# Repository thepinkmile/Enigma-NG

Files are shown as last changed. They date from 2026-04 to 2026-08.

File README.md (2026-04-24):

# Enigma NG: Digital Cryptography Ecosystem

The Enigma-NG is an advanced "Museum-Grade", modular, and historically-accurate digital recreation of the world’s most iconic encryption machines.
Powered by a **Raspberry Pi Compute Module 5 (CM5)**, this system controls a hardware stack of up to 30 custom CPLD-based rotors and a physical 64-jack plugboard.
Powered with either USB-C Power Adapter, PoE+ or Smart Battery. It bridges 1940s mechanical heritage with 2026 high-speed digital engineering.

## 🚀 Project Vision

To create a high-fidelity, educational, and industrially robust encryption platform.
The design prioritises classroom safety, professional EMI shielding, and deep hardware visibility for students via an integrated diagnostic bank.
Beyond a simple Enigma clone, this terminal is a **Universal Cipher Engine**. The hardware is designed to emulate:

* **Enigma Variants:** I, M3, M4, and Abwehr.
* **Typex:** The 5-rotor British adaptation with simulated printer output.
* **SIGABA:** The 15-rotor US system using complex 3-bank stepping algorithms.
* **NG-26** The modern digital enigma machine designed and created by Matthew McAtamney-Greenwood.

One of the long-term goals of this project is to introduce the ability to deliver Enigma encrypted data over the network,
and even provide the ability to deliver encrypted files using a base-64 encoding before executing the standard rotor-based encryption.
This end-goal will involve the definition of a new RFC for the "Enigma-Packet-Protocol (EnPP)", which will be a custom specification for this project's ecosystem.

## Tools Used

* **Visual Studio Code:** To manage the Documentation within this repository.
* **Visual Studio:** (Latest Community Edition) To develop the GUI Application.
* **KiCAD 9:** To develop the electrical components and PCB layouts.
* **OnShape:** To create and manage the mechanical designs and assemblies.
* **Yocto:** To create the custom Linux OS with built-in drivers and GUI Application.

## Core Component Overview

* **Controller Board:** Raspberry Pi Compute Module 5 (CM5) carrier board hosting the fixed
  motherboard, external I/O, and service docks.
* **Power Module:** Removable power-conditioning / UPS cartridge with PoE, USB-C, smart-battery
  inputs, eFuse protection, and supercap-backed hold-up.
* **Stator Board:** Removable vertical daughterboard and CPLD routing hub for the rotor stack,
  encoder ports, reflector return, and Settings Board I2C link.
* **Rotor Module:** Repeated smart encryption unit (up to 30 fitted) with local CPLD and position
  sensing.
* **Extension Board:** 5-rotor group bridge used to regenerate JTAG timing and carry power /
  return-path continuity between rotor groups.
* **Reflector Board:** Mandatory passive turnaround board at the end of the rotor chain.
* **Encoder Module:** Single generic 64-line interface board reused in keyboard, lightboard, and
  plugboard encode / decode roles.
* **Settings Board:** Panel-mount switch and RGB indicator board on the shared Stator I2C-1 bus.
* **JTAG Daughterboard:** Internal FT232H-based USB-to-JTAG bridge for programming all system CPLDs.

## Core Requirements

* **Interface:** Controller ↔ Power Module uses three TE 10-position 2.5mm dock connectors; Controller
  ↔ Stator uses two Molex EXTreme Guardian HD hybrid docks.
* **Diagnostics:** Two ENIG diagnostic banks are provided on the Controller for the PM and Stator dock
  interfaces.
* **UI:** .NET 10.0 Cross-platform GUI with:
  * Live power telemetry.
  * Historical resources.
  * 3D graphical visualiser.
  * Configuration programmer (and creator).

## Board Status Snapshot

| Board | Status |
| :--- | :--- |
| Controller Board | In Review |
| Power Module | In Review |
| Stator Board | In Review |
| Rotor Module | In Review |
| Extension Board | In Review |
| Reflector Board | In Review |
| Encoder Module | In Review |
| Settings Board | In Review |
| JTAG Daughterboard | In Review |

---

## 🔌 Hardware Architecture

### 1. Power Module (The Heart)

* **Input:** Triple-input OR-ing between PoE+ 802.3bt Type 4, USB-C 15V PD, and Battery
  11–16.4V via LM74700-Q1 + CSD17483F4T ideal-diode FETs. PoE is explicitly prioritised over
  USB-C; USB-C vs Battery precedence follows the active input voltages unless extra gating is added.
* **PoE:** Fully discrete 802.3bt Type 4 front end — TPS2372-4 (PD interface) + TPS23730 (ACF DC-DC) + Coilcraft POE600F-12LD transformer stage. Implemented 12V power stage capacity: 60W.
* **Protection:** TPS25980 eFuse — 7A ILIM, 11.0V UVLO, 16.9V OVLO, 3mΩ RON. Plus 72°C TCO thermal fuse.
* **Buck:** Dual-phase interleaved LMQ61460-Q1 (×2, 6A each, 12A combined, 400kHz DRSS, 180° SYNC). Effective ripple: 800kHz.
* **LDO:** TPS75733KTTRG3 3V3_ENIG (8.8µVRMS noise, 72dB PSRR, 3A, 2.05 A typical load at 68.3% utilisation).
* **UPS:** LTC3350 supercap manager + 8× Abracon ADCR-T02R7SA256MB (2S4P, 50 F) on 5V_MAIN bus. 50 F at 5.4V → ≥33.5 second hold-up for clean CM5 shutdown.
* **Output Rails:** 5V_MAIN (12A) and 3V3_ENIG (3A — logic, CPLDs, and rotor stack) via 80-pin Samtec ERF8 BtB to Controller Board for distribution.
* **Panel Controls:** SW1 is a rugged latching RGB power toggle (Adafruit 4660) and SW2 is a
  matching 16mm momentary RGB CM5 power button (Adafruit 3350); both are panel-mounted controls
  wired to the Power Module harness.

### 2. Controller Board (The Brain)

* **Module:** Raspberry Pi CM5 (BCM2712) on a custom 6-layer 2oz carrier.
* **Power Input:** 3-way seamless switching (LM74700-Q1 ideal-diode on Power Module).
  * **Smart Battery:** 5-pin Molex Micro-Fit connector (11V-16.4V nominal) with SMBus telemetry + BATT_PRES_N.
  * **PoE+ (802.3bt Type 4):** Power-over-Ethernet delivered through the Power Module discrete
    TPS2372-4 + TPS23730 + POE600F-12LD path. The implemented 12V stage is sized at 60W. Single
    Ethernet cable carries both data and power.
  * **USB-C PD:** 15V USB-C PD negotiated input.
* **Protection:** Over-voltage and over-current protection provided by Power Module eFuse upstream; local reverse-polarity and ESD protection on BtB interface.
* **Rotor Rail:** The rotor stack is powered by the **3V3_ENIG** rail (TPS75733KTTRG3 LDO, 3A) generated on the Power Module; routed to rotor stack via Controller Board → Link-Beta. CM5 GPIO 16
  (ROTOR_EN) gates the LDO enable for sequenced power-up.
* **JTAG Master:** Embedded FT232H (Permanent USB Blaster) on internal USB 2.0.
* **Connectivity:** Native USB 3.0 (SMT), HDMI (SMT), and Gigabit Ethernet.

### 3. JTAG Daughterboard

* **Logic:** FT232H USB-to-JTAG bridge with buffered TCK / TMS drive.
* **Role:** Programs the full 37-device JTAG chain (1 Stator + 6 Encoder + 30 Rotor CPLDs).
* **Mounting:** Small internal hat-style daughterboard on the Controller; no external connectors.

### 4. Stator Board (Nervous System)

* **Role:** Removable vertical daughterboard and electrical backbone of the rotor stack.
* **Routing Hub:** Stator CPLD is the ENC_DATA routing matrix, reflector-map application point, and
  first device in the system JTAG chain.
* **Interconnects:** Hosts the Controller hybrid docks, rotor sockets, reflector / extension return
  connector, six Encoder-module IDC ports, and the Settings Board I2C harness.
* **Peripherals:** Owns the rotor-stack INA219 current monitor, three MCP23017 expanders, and the
  PCA9685 servo PWM driver.

### 5. Encoder Module (Universal Interface)

* **Generic PCB:** One single-sided board reused in six roles: `KBD_ENC`, `LBD_DEC`,
  `PLG_PASS1_DEC`, `PLG_PASS1_ENC`, `PLG_PASS2_DEC`, and `PLG_PASS2_ENC`.
* **Logic:** Intel **MAX II EPM240T100I5N** CPLD per board.
* **HID Path:** Physical keyboard layout is 40 positions (`[a-z0-9+=]` plus left / right Shift),
  while the logical repertoire remains the full 64-character code space.
* **Plugboard Path:** Two decode / encode board pairs provide the two configurable passive plugboard
  passes.

### 6. Settings Board (Configuration Panel)

* **Role:** User-accessible configuration board with 12 panel-mount toggles, 12 RGB LEDs, and a
  `CFG_APPLY` pushbutton.
* **Interface:** Shared Stator I2C-1 bus over a 6-wire harness (`3V3_ENIG`, `5V_MAIN`, `GND`, `SDA`,
  `SCL`, `GND`).
* **Expanders:** MCP23017 devices at `0x23`, `0x24`, and `0x25`.

### 7. Rotor Module (The Engine)

* **Logic:** Intel **MAX II EPM570T100I5N** CPLD.
* **Dimensions:** Ø92 mm PCB / **Ø100 mm shroud outer**.
* **Segments:** 64 characters with **8mm arc width** for high readability.
* **Memory:** 10 pre-loaded bidirectional wiring sets; 4-position DIP switch for "Rotor Identity" selection.
* **Sensing:** FDC2114RGHR capacitive encoder ICs (dual-track, 3+3 per rotor).
* **Tri-Connector Bus:**
  * Power (2x2), JTAG (2x4 Shielded), and Enigma (2x6 Bidirectional Relay) in a "Tripod" layout.
* **Signal Integrity:** **SN74LVC2G125DCUR** buffer on each Extension Board (one per 5-rotor group) for TCK/TMS regeneration.

### 8. Extension Board

* **Role:** Mid-stack bridge inserted between 5-rotor groups in extended builds.
* **JTAG Support:** Re-buffers `TCK` and `TMS` with `SN74LVC2G125DCUR` to restore timing margin for
  the downstream rotor group.
* **Power / Return Path:** Receives `3V3_ENIG` and `GND` through the Extension Port, passes
  `ENC_IN[0:5]`, `ENC_OUT[0:5]`, `SYS_RESET_N`, and `TTD_RETURN`, and avoids a parallel power path
  through the rotor BtB power connector.
* **Scale:** Up to five Extension Boards may be fitted in the full 30-rotor architecture.

### 9. Reflector Board

* **Role:** Passive end-of-stack turnaround board for the final rotor group.
* **Mapping Ownership:** No local CPLD; the Stator CPLD remains responsible for reflector-map
  selection and application.
* **JTAG Return:** Terminates the JTAG daisy-chain and returns `TTD_RETURN` to the Stator through the
  16-pin reflector ribbon.
* **Signal Path:** Returns the 6-bit ENC path back toward the Stator over a separate electrical path
  while keeping the board itself logically passive.

---

## 💻 Software Implementation

### 1. Linux Kernel Driver

* **Interrupt Handling:** High-priority monitoring of the `KEY_EVENT_INT` line.
* **State Mapping:** Maps 6-bit Input/Return Path to `/dev/enigma_state`.
* **Power Telemetry:** Exposes SMBus battery data and PoE status to userspace.
* **JTAG Control:** Executes Boundary Scan (SAMPLE/PRELOAD) upon keypress trigger.

### 2. .NET 10 GUI (The Terminal)

* **Binary File Transfer:** Encrypts files via Base64 encoding/decryption through the hardware rotors.
* **Ethernet/UDP Interface:** Secure 6-bit encrypted UDP streams for remote terminal communication.
* **Power Dashboard:** Real-time monitoring of Battery (SoC/Temp), PoE+, and USB-C sources.
* **Rotor Library Manager:** Visual tool to design custom wiring and flash the 30-rotor stack.
* **Historical Archive:** Educational database of Enigma, Typex, and SIGABA variants.

### 3. VHDL Firmware (The Navigators)

* **Stator CPLD:** Owns the ENC routing matrix, plugboard insertion positions, reflector-map
  application, and source-selection handoff between keyboard and CM5 virtual input.
* **Rotor CPLDs:** Implement the rotor wiring libraries and per-rotor identity selection.
* **Encoder CPLDs:** Provide the encode / decode logic used by the keyboard, lightboard, and both
  plugboard passes.
* **Status:** Board-level hardware architecture is defined in the active design specs; implementation
  planning and pseudo-code remain tracked as open work in `design/Design_Log.md`.

---

## ⚠️ Safety & Design Rules (KiCAD 9)

* **eFuse Latch-off:** Electronic fault protection requires manual power cycle to reset.
* **Soft Start:** SW1 drives the TPS25980 eFuse EN pin; the CM5 separately gates the 3V3_ENIG LDO with ROTOR_EN.
* **ESD Hardening:** TVS diodes on all exposed pins (JTAG, Enigma, and 64-jack lines).
* **Stackup:** Mixed stackup architecture: Controller Board and Power Module are 6-layer boards; the remaining electronics boards are 4-layer / 2oz designs.

---

## 📅 Development Roadmap

1. **Battery connector review:** confirm whether alternative battery-connector options should replace
   or supplement the present Power Module choice.
2. **Encoder board updates:** finish the current Encoder review / update pass and confirm whether any
   structural split work is still required.
3. **Extension follow-up:** review mechanical usage and whether notch-rotation pass-through needs extra
   circuitry.
4. **Coupon / PAS planning:** add and review board-level coupons and acceptance-test hooks across the
   design set.
5. **Deep review rerun:** rerun the review passes after the next material design-document change set.

## Contributions

This is an open-source development project. Contributions are welcomed from all.
When submitting an issue please ensure you provide the SHA commit hash for the version of code that exhibits your issue and provide full replication steps.
For any contributions, please create a Pull Request and ensure useful commit messages are provided.
Once a PR is accepted the changes with be squashed into the current working branch of this repository and your name will be added to the list of contributors.

<!-- readme: collaborators,contributors -start -->
<table>
	<tbody>
		<tr>
            <td align="center">
                <a href="https://github.com/thepinkmile">
                    thepinkmile
                    <br />
                    <sub><b>The Pink Mile Developer</b></sub>
                </a>
            </td>
		</tr>
	<tbody>
</table>
<!-- readme: collaborators,contributors -end -->

## Licensing

For enquiries regarding educational licensing, please contact the maintainer.
This repository is licensed under the GNU GENERAL PUBLIC LICENSE v3.

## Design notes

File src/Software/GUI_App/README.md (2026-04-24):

# Enigma-NG GUI Application

This is the cross-platform GUI application for the Enigma-NG project, built with Avalonia UI and .NET 10.0.

## Project Structure

The project is located in `src/Software/GUI_App/` with the solution file at `src/EnigmaNG.sln`.

## Supported Platforms

- Windows (x64)
- Linux (ARM64) - Optimized for Raspberry Pi CM5 with Raspberry Pi OS

## Prerequisites

- .NET 10.0 SDK
- For Linux/Raspberry Pi:
  - Raspberry Pi OS (Debian-based)
  - X11 or Wayland display server
  - GTK libraries (install with `sudo apt-get install libgtk-3-0`)

## Building

```bash
dotnet build
```

## Running

```bash
dotnet run
```

## Publishing for Raspberry Pi

To create a self-contained executable for Raspberry Pi CM5:

### Using Publish Profile (Recommended)

```bash
dotnet publish /p:PublishProfile=Properties\PublishProfiles\linux-arm64.pubxml
```

### Using Command Line

```bash
dotnet publish -c Release -r linux-arm64 --self-contained --single-file --trimmed --ready-to-run
```

The output will be in `bin/Release/net10.0/linux-arm64/publish/`.

## Features

- MVVM architecture
- Cross-platform UI with Avalonia
- Hardware-accelerated rendering on Linux

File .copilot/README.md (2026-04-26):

# Copilot Session State
This folder contains the canonical GitHub Copilot handoff state for the Enigma-NG project.
**This folder is tracked in version control** and serves as the single source of truth for
resuming work across sessions.
## Purpose
Each Copilot CLI session is assigned a new UUID-based folder under the user profile
(`%USERPROFILE%\.copilot\session-state\<uuid>`). By maintaining a canonical copy here,
the assistant can pick up exactly where it left off in any future session without needing
to hunt through user-profile paths.
## How to use (at the start of a new session)
Tell Copilot:

> "Please read `.copilot/plan.md`, `.copilot/handoff.md`, and the relevant checkpoints in
> `.copilot/checkpoints/` to align yourself with the current project state before we continue."
## Contents
| File | Description |
|---|---|
| `plan.md` | Current session plan — state, open workstreams, critical notes, next steps |
| `handoff.md` | Generic repo-local handoff note for persistent non-design workflow context |
| `agent-scripts/` | Repo-local helper scripts for repeatable Copilot maintenance tasks |
| `checkpoints/index.md` | Chronological list of all checkpoints |
| `checkpoints/NNN-*.md` | Individual checkpoint snapshots (history, work done, technical details) |
## Maintenance
The assistant updates these files at meaningful milestones:

- after each review cycle clean pass
- when a board detailed design is marked complete
- before ending a session (checkpoint save)
- when repo-local handoff notes need consolidation or cleanup

A checkpoint is only complete once the checkpoint markdown, checkpoint index, plan, and any
related handoff artifacts have all been written or synced into this repo-local `.copilot\` folder.
## Version Control
**This folder is tracked in git.** All checkpoint files, plan updates, and handoff-state changes
should be committed alongside design specification changes.

Content here is sanitized to be portable across machines and users:

- repo-relative paths (not machine-specific absolute paths)
- `%USERPROFILE%` placeholders for user-profile references
- no Copilot session UUIDs or credentials

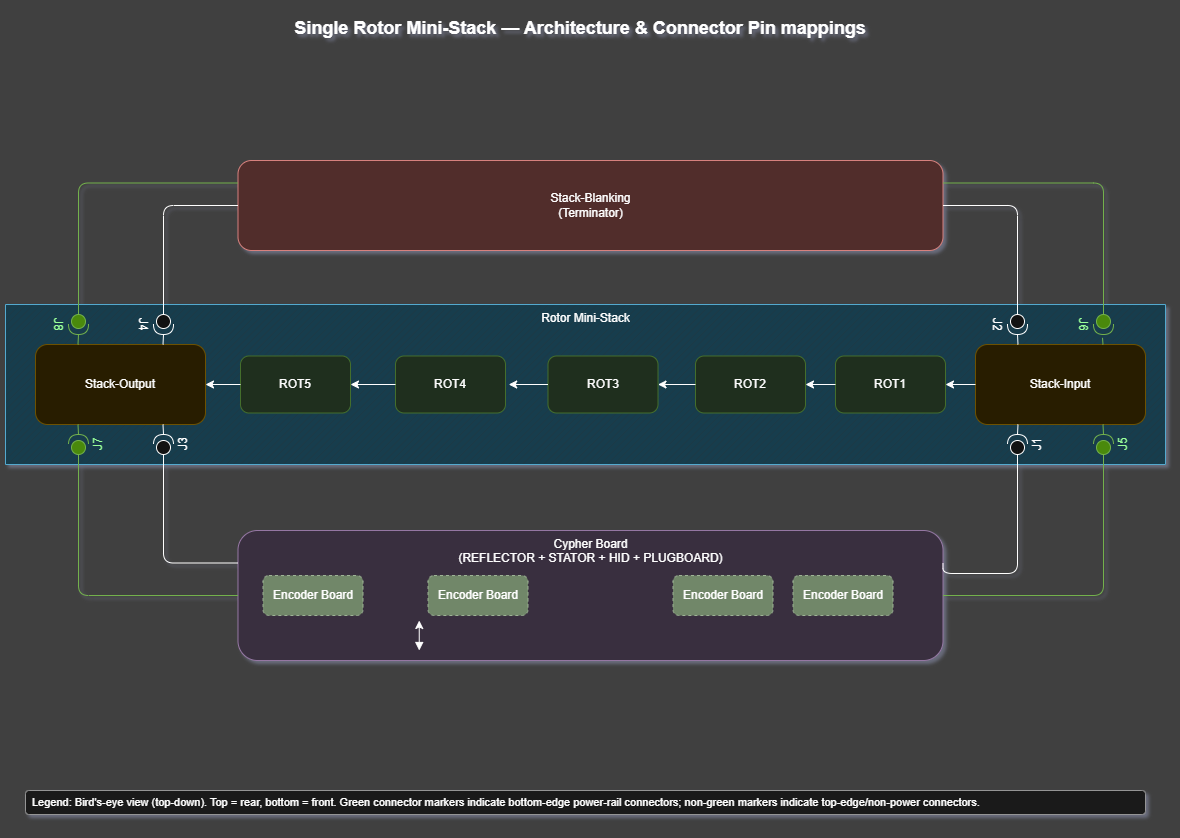
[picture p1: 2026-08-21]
design/Diagrams/renders/cypher-system-layout-Rotor Mini-Stack Architecture.drawio.png

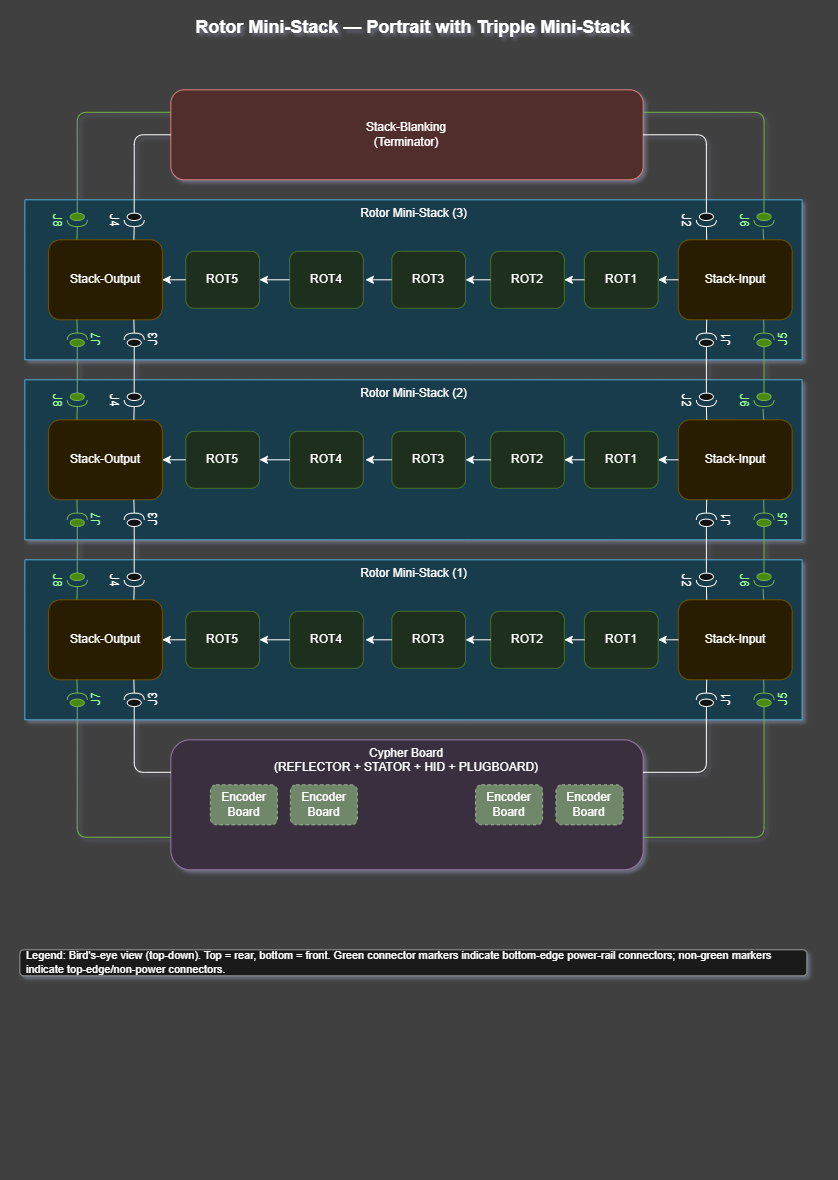
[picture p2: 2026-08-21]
design/Diagrams/renders/cypher-system-layout-Rotor Mini-Stack Multi-Stack.drawio.png

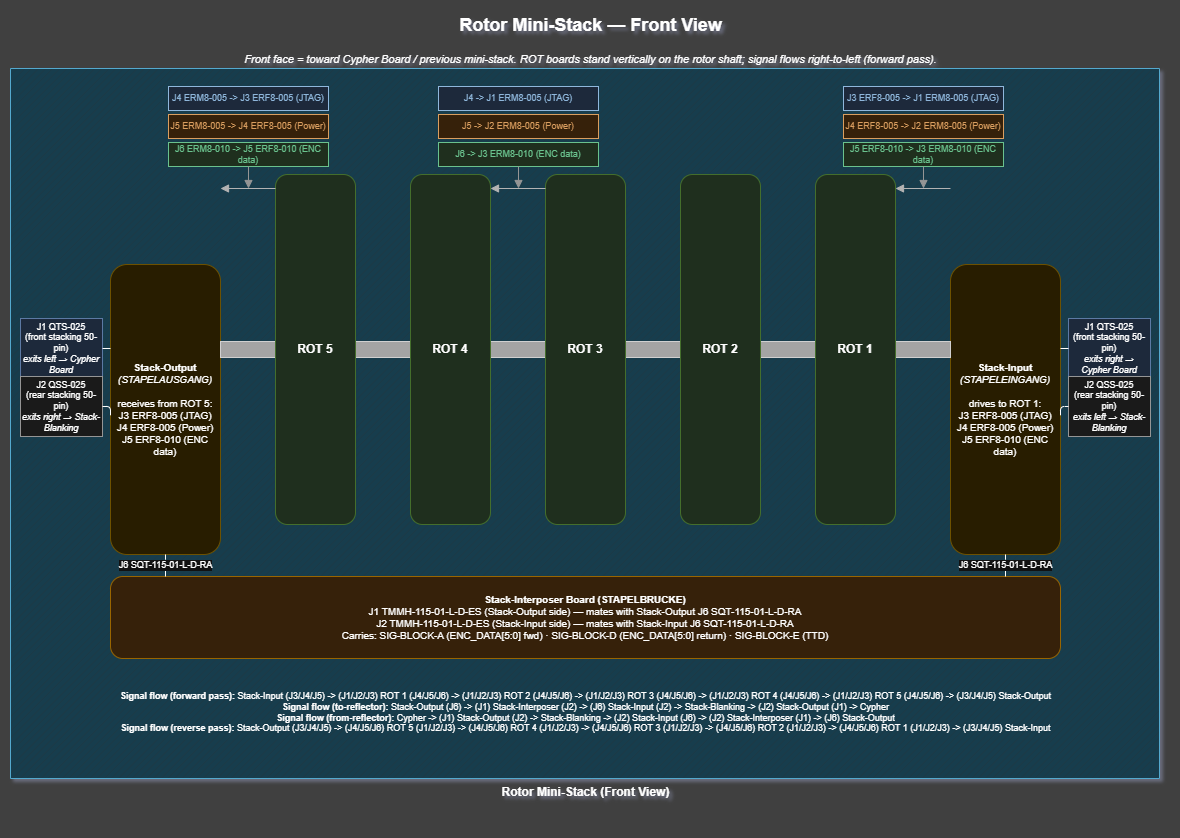
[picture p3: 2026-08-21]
design/Diagrams/renders/cypher-system-layout-Rotor Mini-Stack Front View.drawio.png

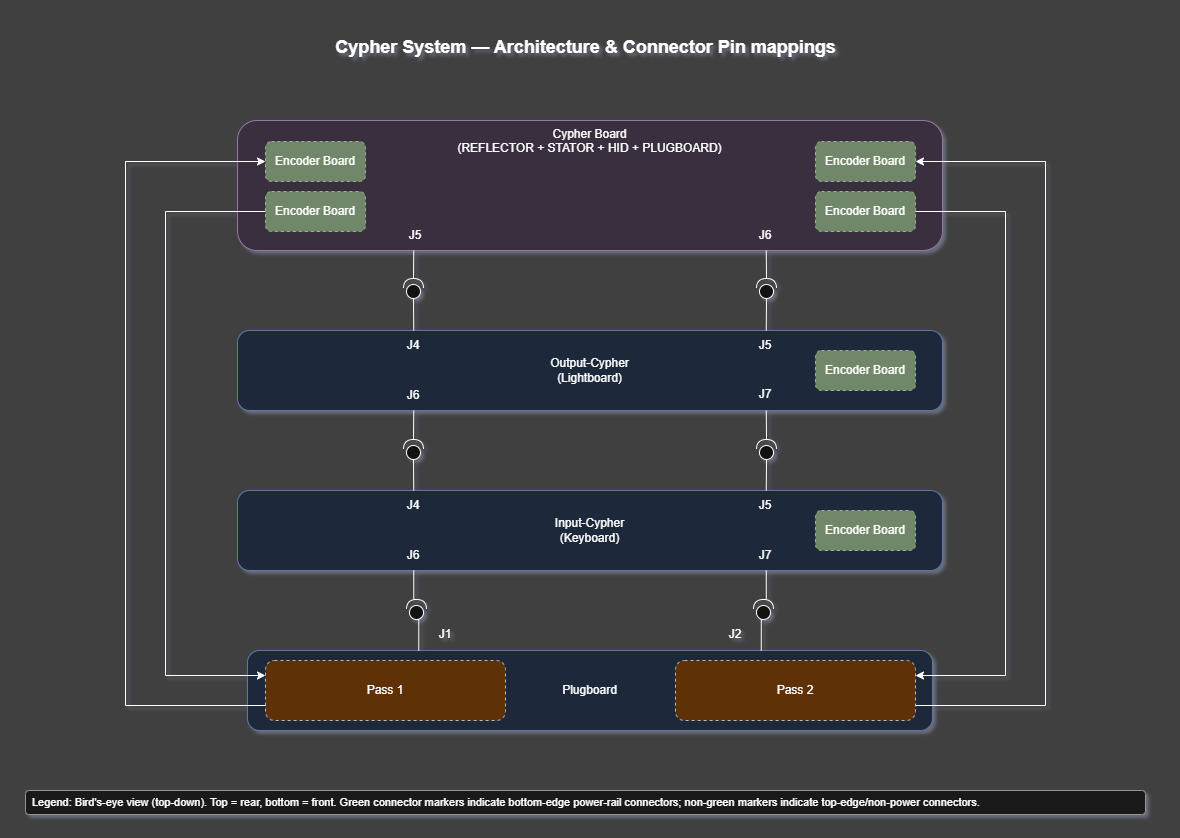
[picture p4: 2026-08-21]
design/Diagrams/renders/cypher-system-layout-Cypher-System Architecture.drawio.png

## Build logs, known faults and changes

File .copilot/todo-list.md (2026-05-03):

# Enigma-NG Project Todo List

> **Canonical deferred-work and open-action reference.** Updated as work progresses.
> See also `.copilot/plan.md` for current workstream status and `.copilot/agent-directives.md` for operational rules.
>
> **Design Log Open Questions** are tracked separately in `design/Design_Log.md` under `## Open Questions`.
> Do not duplicate them here — that file is the authoritative source for formally raised design questions.
>
> **SQL tracking:** At the start of each session, populate the local SQLite `todos` and `todo_deps` tables
> from the SQL Reconstruction Reference section at the bottom of this file. That section is the authoritative
> dependency source; the in-session SQL is a convenience tracker only and does not persist across sessions.

Last updated: 2026-05-03 (rotor-refdes-reallocate + 4 interim electronics review milestones added; Pass 3 fixes in progress)

---

## Open Workstreams (Plan-Level)

Long-running workstreams; tracked in `.copilot/plan.md` Current Open Workstreams table.

| ID | Description | Status | Source |
| --- | --- | --- | --- |
| `extension-mechanical-usage` | Detailed switch/linkage geometry for Extension boundary carry is still needed; architectural answer (shared AM) is locked but physical linkage spec is not | pending | `plan.md` |
| `coupon-testing-review` | Add and review board-level coupons and PAS-oriented test coverage so production boards do not retain test-only hardware. Depends on: `extension-mechanical-usage` (connector changes likely) | pending | `plan.md` |
| `battery-connector-final-review` | Re-confirm Glenair `807-216-00ZNU6-6DY` contact assignment, `BATT_PRES_N` position, reserved-contact behaviour, cable selection, and interposer fit; check ODU AMC NP lead before closing | **🔒 blocked** — awaiting external supplier response | `plan.md` |
| ~~`general-pin-mapping-schematic-capture`~~ | ✅ **COMPLETE** — Footprints now available in KiCAD library; schematic capture can begin | done | `plan.md` |
| `rerun-deep-reviews` | Final pre-V1 cross-discipline deep-review cycle — run only once electrical, mechanical, and software work are complete and each board has a full KiCAD project with exported production Gerbers | pending | `plan.md` |

---

## Electronics Deferrals

| ID | Description | Status | Ref | Source |
| --- | --- | --- | --- | --- |
| `ctlh1-deferred` | Controller CTL-H1 finding: explicitly deferred by user during Pass 2 review cycle | ✅ DONE | — | Resolved checkpoint 076: R1/R2 stale placeholders removed; R3–R6 renumbered R1–R4 |
| `rotor-power-analysis-ministack` | Recalculate Rotor `Board_Layout.md §7` power analysis for mini-stack architecture. Currently assumes a single daisy-chain of 30 rotors (worst-case J2 input 1.65 A at Rotor 1). Architecture uses mini-stacks of max 5 rotors with an Extension Board re-introducing clean 3V3_ENIG at each mini-stack start — worst case is now 5 × 55 mA = 275 mA. Update: worked example, inline table (Rotor 1/15/30 rows), trace width table §7.1, and §7.2 notes. Also verify Extension Board power re-injection connector sizing. | ✅ DONE | DEC-053 | Checkpoint 098: power analysis rewritten for mini-stack; Extension connector under-spec discovered and resolved in checkpoint 099 (BHR-20-VUA → 2BHR-30-VUA) |
| `rotor-esd-tvs` | ✅ **DONE.** PRTR5V0U10AZ placeholder superseded; TPD4E05U06QDQARQ1 selected (reused from PM/CTL — no new part). U5–U12 fully defined in Design_Spec.md §6 and Board_Layout.md. All supplier PNs in Consolidated BOM. | ✅ DONE | — | Resolved prior session; confirmed 2026-05-03 |
| `rotor-variant-refdes-schematic` | ✅ **DONE.** Rotor variant A/B suffix convention agreed and implemented: U3→U3A, U4→U3B; all associated bypass caps (C16A/C17A/C16B/C17B) and resonant-tank components (C22A–C25A/C22B–C25B, L5A–L8A/L5B–L8B) renamed throughout Design_Spec.md, Board_Layout.md, Rotor_26_Char_Design.md, Rotor_64_Char_Design.md, and Consolidated_BOM.md. DEC-052 logged. KiCAD schematic will use U3A/U3B as unique RefDes with N26/N64 project variants selecting DNP flags. | ✅ DONE | DEC-052 | This session (2026-05-01); deferred until schematic capture |
| `display-addon-board` | 🚫 **DEFERRED TO V2.0.** Display add-on board design: J9 (Amphenol F52Q) on Controller is the only fixed connector; display power, touch wiring, and auxiliary harness remain deferred with the add-on board definition | blocked | DEC-033 | `design/Electronics/Controller/Design_Spec.md §8` |
| `cpld-production-replacement` | 🚫 **DEFERRED TO V2.0.** Review replacement CPLD for production stage (current MAX II EPM570 is a prototype-grade selection); update Certification Evidence §7.1 when confirmed | blocked | OA-04 | `design/Standards/Certification_Evidence.md` |
| `connector-thermal-verification` | **✅ DONE.** Thermal / current-capacity verification of active PM and Stator dock connectors (TE `1-1674231-1` / `1123684-7` and Molex `2195630015` / `2195620015`); full derating analysis documented in Certification Evidence §5.1. Temperature exception noted for TE connector (−20°C continuous vs DEFSTAN −40°C target); thermal shock test to −40°C cited as supporting evidence. Formal TE confirmation recommended before DEFSTAN submission. | done | OA-05 | `design/Standards/Certification_Evidence.md §5.1` |
| `rotor-refdes-reallocate` | Rotor board RefDes gap removal: BOM currently runs R2–R7 (no R1 — series termination resistor was never used). Reallocate to R1–R6 with matching updates to `Design_Spec.md` BOM table, `Board_Layout.md` references, and `Consolidated_BOM.md` Rotor rows. All boards must have zero RefDes gaps before `interim-electronics-review-1` can be called complete. | pending | — | 2026-05-03 |
| `full-pn-review` | Full supplier PN review of all BOM entries before schematic capture — a prior session that reduced component package sizes appears to have corrupted supplier PNs on at least two components (ERJ-2RKF1001X, CL05B104KB5NNNC), substituting codes pointing to entirely different parts. A sweep of all DigiKey / Mouser / JLCPCB PNs against their MPNs is required before KiCAD work begins. Depends on: `connector-thermal-verification`, `extension-mechanical-usage`, `battery-connector-final-review`, `ctlh1-deferred`, `rotor-esd-tvs`, `coupon-testing-review` | pending | — | 2026-05-02 supplier PN audit |
| `footprint-requests-pending` | Footprints requested but not yet received; update BOM and library when each arrives: **BAT54** (Diotec SOT-23) — requested, **AC72ABD** (72°C SMD thermal cutoff) — requested, **BMC-Q2AY0600M** (TE 600Ω 0805 AEC-Q200 ferrite bead) — requested, **2BHR-30-VUA** (Adam Tech 30-pin 2×15 IDC box header, JLCPCB C17346400; used at STA:J10, REF:J4, EXT:J7/J8) — requested, **TPS75733KTTRG3** (Texas Instruments 3.3V LDO TO-263-5) — ⚠️ footprint ready, no 3D model yet — download on next session, **MCP121T-450E/LB** (Microchip 4.5V supervisor SC70-3) — ⚠️ footprint ready, no 3D model yet — download on next session. Add further pending requests here as they arise. Depends on: `full-pn-review` | pending | — | 2026-05-02 |

---

## Mechanical Deferrals

Depends on: `prototype-pcb-manufacturing`, `ltc3350-telemetry`, `cpld-timing-load` (all three must be done before any mechanical work can be closed).

| ID | Description | Status | Source |
| --- | --- | --- | --- |
| `rotor-shaft-diameter` | Central shaft hole diameter for Rotor PCBs: Ø10mm nominal; final size TBD once Rotor Actuation Assembly shaft diameter is fixed (8–12mm range) | pending | `design/Mechanical/Rotor/Design_Spec.md`; `design/Electronics/Rotor/Board_Layout.md` |
| `rotor-rolling-element` | Rolling element diameter: TBD; matched set required for even load (±0.01mm) | pending | `design/Mechanical/Rotor/Design_Spec.md` |
| `rotor-alloy-grade` | Rotor disc aluminium alloy grade: TBD — 6061-T6 suggested for machinability; confirm before manufacture | pending | `design/Mechanical/Rotor/Design_Spec.md` |
| `rotor-shaft-mechanism` | Rotor shaft retention mechanism: TBD — pending Rotor Actuation Assembly spec | pending | `design/Mechanical/Rotor/Design_Spec.md` |
| `display-aperture` | 🚫 **DEFERRED TO V2.0.** Main enclosure display aperture dimensions: TBD pending display size selection (up to 10" supported via DSI1); deferred display auxiliary hinge space also unresolved | blocked | `design/Mechanical/Main_Enclosure/Design_Spec.md` |
| `system-assembly-harnesses` | Complete System Assembly cable harness definitions: TBD — 20-pin encoder IDC ribbons, reflector cable, fan cable, User Settings Module I²C ribbon, switch / battery harnesses | pending | `design/Mechanical/Complete_System_Assembly/Design_Spec.md` |
| `system-assembly-connectors` | Complete System Assembly connector list: TBD — TE PM dock, Molex Stator dock, ERF8/ERM8 rotor-family BtB, JST PH servo, JST SH fan, 20-pin IDC encoder, etc. | pending | `design/Mechanical/Complete_System_Assembly/Design_Spec.md` |

---

## Software Deferrals

Depends on: `rerun-deep-reviews` + `prototype-pcb-manufacturing` (both required before SW deferrals can be actioned).

| ID | Description | Status | Ref | Source |
| --- | --- | --- | --- | --- |
| `ltc3350-telemetry` | LTC3350 I²C telemetry support in Linux OS power-management driver: deferred to Software PoC stage, pending hardware availability | pending | DEC-025 | `design/Software/Linux_OS/Power_Management.md §2` |
| `cpld-timing-load` | CPLD Encoder Logic timing and electrical load characterisation (propagation delays, fanout, drive current): deferred until first prototype boards exist for measurement | pending | — | `design/Software/CPLD_Logic/Encoder_Logic.md §2` |

---

## Standards & Certification Actions

Items from `design/Standards/Certification_Evidence.md §8`. All depend on `prototype-system-complete`.

| SQL ID | DA Ref | Description | Priority | Status |
| --- | --- | --- | --- | --- |
| `da-01` | DA-01 | If coupon-based diagnostic access is introduced, exposed ENIG pads require dedicated ESD protection or documented justification before production release and classroom deployment | Post-coupon design | open |
| `da-02` | DA-02 | ESD policy for classroom deployment variant: define which internal BtB-accessible connections require additional ESD protection in educational / student-access configuration | Pre-production | open |
| `da-03` | DA-03 | Full consistency documentation pass: legacy Link-Alpha / Link-Beta references must remain historical-only after DEC-038; verify any new docs added use TE PM dock / Molex Stator dock naming | Ongoing | open |
| `da-04` | DA-04 | Update Consolidated BOM with all locked Power Module components *(may be superseded by the 2026-05 BOM restructure — verify against current `Consolidated_BOM.md` before actioning)* | Post-eFuse lock | review needed |
| `compliance-testing` | — | Sending final review prototype for Environmental and EMC testing to get required certification documentation | Pre-production | pending |

---

## Project Milestones

Top-level milestones that gate v1.0 release. Descriptions TBD — to be confirmed with user before closing.

| ID | Description | Status | Depends on |
| --- | --- | --- | --- |
| `review-mounting-holes` | Verify mounting hole count and board-specific location for every board during schematic capture and PCB layout stage. Cannot be fully defined until KiCAD layout is complete. Known placements: USM = 4 corners; Extension = bottom corners + middle-centre + top-centre. Extension AM standoff holes (quantity/position/part TBD). Hole type and pad spec per GRS §4.2. | pending | `interim-electronics-review-1`, `coupon-testing-review` |
| `interim-electronics-review-1` | **Review gate 1 — Pass 3 fixes verified.** All pass-3 fix todos (fix1–fix19) and `rotor-refdes-reallocate` must be complete. Verify no RefDes gaps on any board, all pass-3 findings resolved, and documentation consistent before proceeding to schematic capture / footprint work. | pending | All fix1–fix19 + `rotor-refdes-reallocate` |
| `interim-electronics-review-2` | **Review gate 2 — Post-coupon review.** Coupon strategy verified, all mounting hole locations finalised, BOM ready for full PN review. | pending | `interim-electronics-review-1`, `coupon-testing-review`, `review-mounting-holes` |
| `interim-electronics-review-3` | **Review gate 3 — Post-schematic / pre-prototype manufacturing.** Schematic capture, footprint assignment, and full PN review complete. Final electronics design gate before committing to prototype PCB manufacturing. | pending | `interim-electronics-review-2`, `full-pn-review`, `footprint-requests-pending` |
| `interim-electronics-review-4` | **Review gate 4 — Pre-production run.** Prototype system testing complete and all prototype-phase findings resolved. Final gate before releasing to production manufacturing. | pending | `prototype-system-complete`, `compliance-testing` |
| `prototype-pcb-manufacturing` | Process prototype PCB manufacturing through JLCPCB: (1) Generate manufacturing pack (gerber, pick & place, LCSC BOM); (2) Global Sourcing Part Order; (3) Consignment Parts Order; (4) Board Orders (one per board); (5) Receive Boards and Inspect; (6) Run Board PAS Testing | pending | `rerun-deep-reviews`, `review-mounting-holes`, `interim-electronics-review-3` |
| `prototype-system-complete` | Verification of full system and issuing all design documents, test procedures and guides as version 1.0 complete | pending | All SW & Mech deferrals, `rerun-deep-reviews` |
| `release-candidate-production` | Process final draft design for production testing (via PCBWay or JLCPCB). Same subtasks as `prototype-pcb-manufacturing`: (1) Generate manufacturing pack; (2) Global Sourcing Part Order; (3) Consignment Parts Order; (4) Board Orders (one per board); (5) Receive Boards and Inspect; (6) Run Board PAS Testing | pending | `prototype-system-complete`, `compliance-testing`, `interim-electronics-review-4` |
| `version-one-complete` | All version 1.0 documents issued. Conduct lessons learned from v1.0 and create a new todo-list to refine the design for a version 2.0 machine | pending | `da-01`, `da-02`, `da-03`, `da-04`, `release-candidate-production` |

---

## Dependency Overview

```
fix1-fix19 + rotor-refdes-reallocate
  --> interim-electronics-review-1
        --> interim-electronics-review-2 (also needs: coupon-testing-review, review-mounting-holes)
              --> interim-electronics-review-3 (also needs: full-pn-review, footprint-requests-pending)
                    --> prototype-pcb-manufacturing (also needs: rerun-deep-reviews, review-mounting-holes)

rotor-variant-refdes-schematic
  --> rotor-esd-tvs
        --> full-pn-review (also needs: extension-mechanical-usage,
              |              battery-connector-final-review [blocked - awaiting supplier],
              |              ctlh1-deferred, coupon-testing-review,
              |              connector-thermal-verification)
              --> footprint-requests-pending
                    --> rerun-deep-reviews --+
                          |                  |
                          |--> ltc3350-telemetry (also needs: prototype-pcb-manufacturing)
                          --> cpld-timing-load  (also needs: prototype-pcb-manufacturing)
                                --> [all mechanical deferrals] (also need: prototype-pcb-manufacturing)
                                      --> prototype-system-complete
                                            --> da-01, da-02, da-03, da-04
                                                  --> compliance-testing
                                                        |--> interim-electronics-review-4
                                                        |      --> release-candidate-production
                                                        --> release-candidate-production (also needs: prototype-system-complete)
                                                               --> version-one-complete
                                                                     (also needs: da-01-da-04)

v2.0 deferred (blocked): display-addon-board, display-aperture, cpld-production-replacement
Currently ready (no pending deps): connector-thermal-verification, ctlh1-deferred,
  extension-mechanical-usage, rotor-variant-refdes-schematic
  [coupon-testing-review depends on extension-mechanical-usage]
  [battery-connector-final-review excluded -- blocked awaiting supplier response]
  [prototype-pcb-manufacturing excluded -- depends on rerun-deep-reviews + interim-electronics-review-3]
  [release-candidate-production excluded -- depends on compliance-testing + interim-electronics-review-4]
```

---

## SQL Reconstruction Reference

At session start, run these INSERT statements to reconstruct the `todos` and `todo_deps` tracking tables.
Use `INSERT OR IGNORE` to make the script idempotent (re-runnable without error).

### Todos

```sql
INSERT OR IGNORE INTO todos (id, title, status) VALUES
-- Open Workstreams
('extension-mechanical-usage',        'Extension mechanical linkage spec',             'pending'),
('coupon-testing-review',             'Board-level coupon & PAS test coverage',        'pending'),
('battery-connector-final-review',    'Battery connector final review',                'blocked'),
('general-pin-mapping-schematic-capture', 'General pin mapping / schematic capture',  'done'),
('rerun-deep-reviews',                'Final pre-V1 deep review cycle',               'pending'),
-- Electronics Deferrals
('ctlh1-deferred',                    'Controller CTL-H1 deferred finding',           'done'),
('rotor-power-analysis-ministack',    'Recalculate Rotor Board_Layout §7 power analysis for mini-stack (max 5 rotors per stack)', 'done'),
('rotor-esd-tvs',                     'Rotor ESD TVS (PRTR5V0U10AZ) sourcing',       'done'),
('rotor-variant-refdes-schematic',    'Rotor variant U3/U4 KiCAD DNF approach',       'pending'),
('rotor-refdes-reallocate',           'Rotor RefDes gap removal: R2-R7 -> R1-R6',    'pending'),
('display-addon-board',               'Display add-on board (v2.0)',                  'blocked'),
('cpld-production-replacement',       'CPLD production replacement review (v2.0)',    'blocked'),
('connector-thermal-verification',    'Connector thermal/current derating',           'pending'),
('full-pn-review',                    'Full supplier PN sweep pre-schematic',         'pending'),
('footprint-requests-pending',        'Outstanding footprint requests / downloads',   'pending'),
-- Mechanical Deferrals
('rotor-shaft-diameter',              'Rotor PCB shaft hole diameter',                'pending'),
('rotor-rolling-element',             'Rotor rolling element diameter spec',          'pending'),
('rotor-alloy-grade',                 'Rotor disc alloy grade selection',             'pending'),
('rotor-shaft-mechanism',             'Rotor shaft retention mechanism',              'pending'),
('display-aperture',                  'Main enclosure display aperture (v2.0)',       'blocked'),
('system-assembly-harnesses',         'System Assembly harness definitions',          'pending'),
('system-assembly-connectors',        'System Assembly connector list',               'pending'),
-- Software Deferrals
('ltc3350-telemetry',                 'LTC3350 I2C telemetry Linux driver',           'pending'),
('cpld-timing-load',                  'CPLD timing & load characterisation',          'pending'),
-- Standards & Certification
('da-01',                             'DA-01: Coupon ESD protection requirement',     'pending'),
('da-02',                             'DA-02: Classroom deployment ESD policy',       'pending'),
('da-03',                             'DA-03: Connector naming consistency pass',     'pending'),
('da-04',                             'DA-04: Consolidated BOM PM component update',  'pending'),
('compliance-testing',               'Sending final review prototype for Environmental and EMC testing to get required certification documentation.', 'pending'),
-- Project Milestones
('review-mounting-holes',             'Verify mounting hole count and board-specific location for every board during schematic capture and PCB layout stage. Cannot be fully defined until KiCAD layout is complete.', 'pending'),
('interim-electronics-review-1',      'Review gate 1: pass 3 fixes + rotor-refdes-reallocate complete; no RefDes gaps; all pass-3 findings resolved.', 'pending'),
('interim-electronics-review-2',      'Review gate 2: post-coupon review; mounting holes finalised; BOM ready for full PN review.', 'pending'),
('interim-electronics-review-3',      'Review gate 3: post-schematic / pre-prototype; schematic, footprints, full PN review complete.', 'pending'),
('interim-electronics-review-4',      'Review gate 4: pre-production; prototype testing complete; final electronics gate before production run.', 'pending'),
('prototype-pcb-manufacturing','Process prototype PCB manufacturing through JLCPCB: (1) Generate manufacturing pack (gerber, pick & place, LCSC BOM); (2) Global Sourcing Part Order; (3) Consignment Parts Order; (4) Board Orders (one per board); (5) Receive Boards and Inspect; (6) Run Board PAS Testing',        'pending'),
('prototype-system-complete',         'Verification of full system and issuing all design documents, test procedures and guides as version 1.0 complete.',          'pending'),
('release-candidate-production',      'Process final draft design for production testing (via PCBWay or JLCPCB). Same subtasks as prototype-pcb-manufacturing: (1) Generate manufacturing pack (gerber, pick & place, BOM); (2) Global Sourcing Part Order; (3) Consignment Parts Order; (4) Board Orders (one per board); (5) Receive Boards and Inspect; (6) Run Board PAS Testing.',       'pending'),
('version-one-complete',              'All version 1.0 documents issued. Conduct lessons learned from v1.0 and create a new todo-list to refine the design for a version 2.0 machine.',              'pending');
```

### Dependencies

```sql
INSERT OR IGNORE INTO todo_deps (todo_id, depends_on) VALUES
-- rotor chain
('rotor-power-analysis-ministack',  'rotor-variant-refdes-schematic'),
('rotor-esd-tvs',                   'rotor-variant-refdes-schematic'),
-- full-pn-review prerequisites (all 6 must complete first)
('full-pn-review',              'connector-thermal-verification'),
('full-pn-review',              'extension-mechanical-usage'),
('full-pn-review',              'battery-connector-final-review'),
('full-pn-review',              'ctlh1-deferred'),
('full-pn-review',              'rotor-esd-tvs'),
('full-pn-review',              'coupon-testing-review'),
-- footprint gated by full-pn-review
('footprint-requests-pending',  'full-pn-review'),
-- deep reviews gated by footprints
('rerun-deep-reviews',          'footprint-requests-pending'),
-- software deferrals need deep reviews + prototype hardware
('ltc3350-telemetry',           'rerun-deep-reviews'),
('ltc3350-telemetry',           'prototype-pcb-manufacturing'),
('cpld-timing-load',            'rerun-deep-reviews'),
('cpld-timing-load',            'prototype-pcb-manufacturing'),
-- mechanical deferrals need prototype hardware + both SW deferrals
('rotor-shaft-diameter',        'prototype-pcb-manufacturing'),
('rotor-shaft-diameter',        'ltc3350-telemetry'),
('rotor-shaft-diameter',        'cpld-timing-load'),
('rotor-rolling-element',       'prototype-pcb-manufacturing'),
('rotor-rolling-element',       'ltc3350-telemetry'),
('rotor-rolling-element',       'cpld-timing-load'),
('rotor-alloy-grade',           'prototype-pcb-manufacturing'),
('rotor-alloy-grade',           'ltc3350-telemetry'),
('rotor-alloy-grade',           'cpld-timing-load'),
('rotor-shaft-mechanism',       'prototype-pcb-manufacturing'),
('rotor-shaft-mechanism',       'ltc3350-telemetry'),
('rotor-shaft-mechanism',       'cpld-timing-load'),
('system-assembly-harnesses',   'prototype-pcb-manufacturing'),
('system-assembly-harnesses',   'ltc3350-telemetry'),
('system-assembly-harnesses',   'cpld-timing-load'),
('system-assembly-connectors',  'prototype-pcb-manufacturing'),
('system-assembly-connectors',  'ltc3350-telemetry'),
('system-assembly-connectors',  'cpld-timing-load'),
-- prototype-system-complete needs all SW and Mech deferrals + deep reviews
('prototype-system-complete',   'rerun-deep-reviews'),
('prototype-system-complete',   'ltc3350-telemetry'),
('prototype-system-complete',   'cpld-timing-load'),
('prototype-system-complete',   'rotor-shaft-diameter'),
('prototype-system-complete',   'rotor-rolling-element'),
('prototype-system-complete',   'rotor-alloy-grade'),
('prototype-system-complete',   'rotor-shaft-mechanism'),
('prototype-system-complete',   'system-assembly-harnesses'),
('prototype-system-complete',   'system-assembly-connectors'),
-- DA actions depend on prototype-system-complete
('da-01',                       'prototype-system-complete'),
('da-02',                       'prototype-system-complete'),
('da-03',                       'prototype-system-complete'),
('da-04',                       'prototype-system-complete'),
-- compliance-testing depends on all DA actions
('compliance-testing',          'da-01'),
('compliance-testing',          'da-02'),
('compliance-testing',          'da-03'),
('compliance-testing',          'da-04'),
-- prototype-pcb-manufacturing depends on rerun-deep-reviews, review-mounting-holes, and interim-electronics-review-3
('prototype-pcb-manufacturing', 'rerun-deep-reviews'),
('review-mounting-holes',       'rerun-deep-reviews'),
('prototype-pcb-manufacturing', 'review-mounting-holes'),
('prototype-pcb-manufacturing', 'interim-electronics-review-3'),
-- interim-electronics-review-1 gates (fix1-fix19 listed individually + rotor-refdes-reallocate)
-- Note: fix1-fix19 are session-transient pass-3 fix todos and not reconstructed here;
-- add them manually per session. The structural dep is rotor-refdes-reallocate.
('interim-electronics-review-1', 'rotor-refdes-reallocate'),
-- interim-electronics-review-2 gates
('interim-electronics-review-2', 'interim-electronics-review-1'),
('interim-electronics-review-2', 'coupon-testing-review'),
('interim-electronics-review-2', 'review-mounting-holes'),
-- interim-electronics-review-3 gates
('interim-electronics-review-3', 'interim-electronics-review-2'),
('interim-electronics-review-3', 'full-pn-review'),
('interim-electronics-review-3', 'footprint-requests-pending'),
-- interim-electronics-review-4 gates
('interim-electronics-review-4', 'prototype-system-complete'),
('interim-electronics-review-4', 'compliance-testing'),
-- release-candidate-production depends on prototype-system-complete + compliance-testing + interim-electronics-review-4
('release-candidate-production', 'prototype-system-complete'),
('release-candidate-production', 'compliance-testing'),
('release-candidate-production', 'interim-electronics-review-4'),
-- version-one-complete needs all DA actions + release candidate
('version-one-complete',        'da-01'),
('version-one-complete',        'da-02'),
('version-one-complete',        'da-03'),
('version-one-complete',        'da-04'),
('version-one-complete',        'release-candidate-production');
```

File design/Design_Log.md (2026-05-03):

# Enigma-NG Design Decision Log

**Status:** Active
**Project:** Enigma-NG
**Author:** Izzyonstage & GitHub Copilot
**Version:** v.0.1.0
**Associated Hardware Revision:** Rev A
**Last Updated:** 2026-04-26

This file records key architectural and component decisions made during the design of the Enigma-NG system. Each entry captures the decision taken, the rationale behind it, the alternatives that were
considered, and any constraints or caveats that future designers should be aware of.

Entries are numbered sequentially as **DEC-NNN**. Where a decision supersedes a previous one, the earlier entry is updated with a cross-reference.

---

## DEC-001 — 3V3_ENIG Used Throughout; 3V3_SYSTEM Removed from BtB Interconnect

- **Status:** Obsolete — superseded by DEC-037
- **Date:** 2025
- **Category:** Electrical
- **Area:** Power Module, Controller Board, Link-Alpha connector

### Decision

The `3V3_SYSTEM` rail (sourced from the CM5 on the Controller Board) is **not** routed to the Power Module over the Link-Alpha BtB connector. All 3.3V logic within the Power Module (RJ45 LED anodes,
I2C pull-ups, BATT_PRES_N pull-up, reset pull-up) is powered by `3V3_ENIG`, generated locally by the Power Module LDO (U7).

### Rationale

- `3V3_SYSTEM` is a CM5-derived rail intended only for external peripheral interfaces (Ethernet, HDMI, USB 3.0 ports). Using it to power internal power-module logic would create a cross-domain

  dependency and complicate sequencing.

- Generating `3V3_ENIG` locally on the Power Module gives a clean, independently-controlled 3.3V supply that is always present when the Power Module is powered, regardless of CM5 boot state.
- Removing `3V3_SYSTEM` from the Link-Alpha connector freed pins 21–24, which were reallocated to extend the 5V_MAIN delivery cluster and GND return path.

### Alternatives Considered

- Route `3V3_SYSTEM` from CM5 over Link-Alpha and use it for RJ45 logic. Rejected: cross-domain dependency, sequencing risk, wasted connector pins.
- Use a second small LDO on the Controller Board to produce a local 3.3V for CM5-adjacent logic. Rejected: unnecessary complexity given `3V3_ENIG` already exists.

### Impact

- Pins 21–22: Reassigned from 3V3_SYSTEM → **5V_MAIN** (supplemental power pins)
- Pins 23–24: Reassigned from 3V3_SYSTEM → **GND** (supplemental return path)
- Combined 5V_MAIN capacity: 18 pins × 0.5A = **9A** (was 16 pins = 8A)
- Legacy Controller probe-access concept Pin 14: Reassigned from 3V3_SYSTEM → **SW_LED_CTRL (GPIO 20)** (subsequently updated; see DEC-009)

---

## DEC-002 — PoE Option A2 Selected: Coilcraft POE600F-12LD

- **Status:** Decided
- **Date:** 2025
- **Category:** Electrical
- **Area:** Power Module PoE subsystem, T2 transformer, TPS23730 feedback network

### Decision

The PoE transformer T2 uses a **Coilcraft POE600F-12LD** off-the-shelf ACF transformer (12V output, 60W, 200kHz, ≥1500Vrms isolation, SMT package). The remainder of the PoE chain uses TPS2372-4
(802.3bt Type 4 PD interface) and TPS23730 (ACF controller), with TPS23730 feedback resistors adjusted for the 12V output.

### Rationale

- Replaces a custom-wound transformer design (Option A: 15V, 8–16 week lead time, ~£35–46 BOM) with a catalogue part available from Coilcraft Direct.
- Off-the-shelf: **£3.54 qty-1, ~£1.86 volume**, in stock. Lead time: days not weeks.
- Same ACF topology as the custom design — only feedback resistors change. No PCB layout changes to high-current paths.
- 12V output falls within the TPS25980 eFuse UVLO/OVLO window (11V – 16.9V) with no additional buck stage needed.

### Alternatives Considered

- **Option A (Custom T2, 15V):** Higher voltage headroom. Rejected: custom winding, long lead time, cost.
- **Option C (Silvertel Ag59812-LPB integrated module):** Higher integration, 95% efficiency, ~£19–27. Rejected: higher cost, fixed form factor, less flexibility for thermal management, vendor

  lock-in.

- **Kinetic Technologies KPM5912:** 85W, 93% efficiency. Rejected: not stocked by any UK/EU distributor.

### Key Parameters

| Parameter | Value |
| --- | --- |
| Part | Coilcraft POE600F-12LD |
| Output | 12V nominal |
| Power | 60W (Type 4 PD, 72W class) |
| Isolation | ≥1500Vrms |
| Topology | Active Clamp Flyback (ACF) |
| Package | SMT |
| Price (qty-1) | ~£3.54 |

---

## DEC-003 — PoE Output 12V; OR-ing Priority Logic Required

- **Status:** Decided
- **Date:** 2025
- **Category:** Electrical
- **Area:** Power Module PoE output, OR-ing diode (LM74700-Q1), eFuse input

### Decision

PoE outputs 12V (not 15V) into the OR-ing stage. Because 12V < 15V USB-C input, passive OR-ing would always prefer USB-C and ignore PoE. Active enable logic is implemented: the TPS2372-4 `/PG` signal
drives the LM74700-Q1 gate control low when PoE is live, disabling the USB-C path.

### Rationale

- PoE is the primary field power source when no USB-C adapter is connected. It must not be silently overridden by USB-C passthrough.
- TPS2372-4 `/PG` (power good, active low) is a clean indicator of a live 802.3bt PoE session.
- LM74700-Q1 already provides the USB-C ideal diode function; gating its enable is a minimal-change approach.

### Constraints

- PoE UVLO: 11V. eFuse UVLO: 11V. No margin at UVLO floor — PoE cable must be within 1V drop budget.
- eFuse ILIM utilisation at 12V worst case: 4.67A / 7A = **66.7%** ✓ (within 75% derating target).

---

## DEC-004 — Supercap Charge Current 0.5A Under PoE

- **Status:** Superseded by DEC-029 (cell specification updated; 0.5A charge current constraint retained)
- **Date:** 2025
- **Category:** Electrical
- **Area:** LTC3350 supercap charger, PoE power budget

### Decision

When running on PoE (802.3bt Type 4, 72W budget), the supercap charge current is reduced to **0.5A** (vs. up to 2A on USB-C/Battery).
This limits peak PoE utilisation to 73.9% (53.2W / 72W) — within the 75% design rule ✓ (see Certification_Evidence §3.5).

### Rationale

- Full 2A supercap charging on PoE would push utilisation to ~98%, leaving <2W margin for transient loads.
- 0.5A charge current charges the **8× 25F** supercap bank (2S4P, 50F total — Abracon ADCR-T02R7SA256MB) in approximately 9 minutes from depleted.
- Normal system usage is expected to exceed 30–45 minutes per session (startup + configuration + use), making a 2-minute charge time acceptable.
- This limitation should be documented in the User Manual with guidance that maximum system load is not recommended during the initial PoE power-up window.

### Constraints

- Steady-state PoE load (after caps charged): 50.3W / 72W = **69.9%** utilisation ✓

---

## DEC-005 — TPS25980 eFuse Replaces TPS259474L

- **Status:** Decided
- **Date:** 2025
- **Category:** Electrical
- **Area:** Power Module eFuse (U1)

### Decision

The input eFuse uses a **TPS25980** (7A ILIM, silicon-fixed 16.9V OVLO) rather than the originally considered TPS259474L (5.5A ILIM).

### Rationale

- TPS259474L 5.5A limit is insufficient for worst-case USB-C 15V path at 75W: 75W / 15V = 5.0A + 10% derating = 5.5A — already at the device limit with no headroom.
- TPS25980 (TPS259804ONRGER) provides 7A ILIM (programmed via R3 = 210 Ω) and silicon-fixed 16.9V OVLO, which neatly caps the battery charge voltage window.

### OVLO Constraint

- eFuse OVLO is **16.9V silicon-fixed** (TPS259804ONRGER — no external programming resistor).
- BMS must be configured for **4.1V/cell maximum charge (16.4V for 4S)** to maintain a ≥0.5V margin.
- BMS configurations using 4.2V/cell (16.8V) are not compatible with this eFuse and must not be used.

### ⚠️ Variant Lock — Do NOT change this MPN

The TPS25980 family uses a digit after `TPS25980` to select the OVLO behaviour:

| Variant | OVLO | Status |
| --- | --- | --- |
| **TPS259804ONRGER** | **16.9V silicon-fixed** | ✅ **CORRECT — use this** |
| TPS259807 | No OVLO feature | ❌ WRONG — do not use |
| TPS259803 | No OVLO feature | ❌ WRONG — do not use |

This variant has been erroneously swapped to TPS259807 in previous review rounds.
The `04` digit must not be changed without explicit documented justification.

---

## DEC-006 — STUSB4500 Negotiates 15V/5A (75W)

- **Status:** Decided
- **Date:** 2025
- **Category:** Electrical
- **Area:** Power Module USB-C PD handshake (STUSB4500), USB-C adapter requirement

### Decision

The STUSB4500 standalone PD sink is programmed to negotiate **15V/5A (75W)** from the wall adapter or USB-C PD source. Earlier documentation incorrectly stated 15V/3A.

### Rationale

- 3A (45W) is insufficient for worst-case system load (CM5 at 25W + rotors + supercap charging).
- 5A (75W) provides headroom and aligns with the 75% derating target at the eFuse.
- Users must use a USB-C PD adapter rated for at least 75W (15V/5A or 20V/5A with appropriate negotiation cap).

---

## DEC-007 — Dual Interleaved LMQ61460-Q1 5V Buck (12A)

- **Status:** Decided
- **Date:** 2025
- **Category:** Electrical
- **Area:** Power Module 5V Buck (U2A/U2B)

### Decision

Two **LMQ61460-Q1** buck regulators are used in a **dual interleaved** configuration, providing a combined **12A** output at 5V. Earlier documentation referenced a single LM61460-Q1 (6A).

### Rationale

- Single 6A device is insufficient for CM5 at 25W (5A) + other 5V loads.
- Interleaved dual phase reduces input/output ripple and distributes thermal load.
- 12A capacity aligns with the 9A+ delivery capability of the updated Link-Alpha pin cluster.

---

## DEC-008 — TPS25750 Emulates 5V/5A PD Profile to CM5

> ⚠️ **Superseded by DEC-012** — TPS25750 replaced with TPS25751DREFR. See DEC-012.

- **Status:** Superseded by DEC-012
- **Date:** 2025
- **Category:** Electrical
- **Area:** CM5 USB-C PD emulator (TPS25750)

### Decision

The TPS25750 PD emulator advertises a **5V/5A** profile to the CM5 internal USB-C port.

### Rationale

- The CM5 Linux OS will generate a "low power" warning if PD negotiation does not complete at or above 5V/5A (25W).
- 5V/5A is the minimum advertisement to suppress this warning and allow unrestricted CPU/GPU boost operation.

---

## DEC-009 — Legacy Controller Probe-Access Pin 14 Reassigned to SW_LED_CTRL

- **Status:** Decided
- **Date:** 2025 (GND); superseded by final design (SW_LED_CTRL)
- **Category:** Electrical
- **Area:** Historical Controller bring-up probe-access concept

> **Supersession note:** Historical-only. See **DEC-040** for the current rule that all Diagnostics
> Banks are removed from the active design specs and will only be reconsidered later during the
> coupon implementation review.

### Decision

The legacy Controller probe-access concept pin 14 was initially reassigned from `3V3_SYSTEM` to
**GND**, following the removal of the `3V3_SYSTEM` rail from all BtB interconnects (see DEC-001).
In the subsequent design pass that added `SW_LED_CTRL` (GPIO 20) to the Link-Alpha signal set,
pin 14 was reallocated to **SW_LED_CTRL** to expose the LED-arbitration handshake at the historical
bring-up probe point.

**Final assignment:** Legacy Controller probe-access concept pin 14 = `SW_LED_CTRL` (GPIO 20, CTRL
→ PM, HIGH = CM5 in control of SW1 RGB LED).

### Rationale

- `3V3_SYSTEM` is no longer available at the Power Module side of this debug header.
- `SW_LED_CTRL` is a useful bring-up observation point — it shows whether the CM5 has taken control
  of the RGB LED from the hardware oscillator fallback path.
- GND is freely available on pins 19–20; a redundant GND at pin 14 added no diagnostic value.

---

## DEC-010 — INC-14 DEFERRED: Legacy Probe-Access ESD Protection (Post-Prototype)

- **Status:** Deferred — Accepted risk for prototype stage
- **Date:** 2025
- **Category:** Electrical
- **Area:** Historical Controller bring-up probe-access concept

> **Supersession note:** Historical-only. See **DEC-040** for the current rule that all Diagnostics
> Banks are removed from the active design specs and will only be reconsidered later during the
> coupon implementation review.

### Decision

ESD protection on the historical probe-access concept is **deferred** to post-prototype evaluation.
No TVS diodes or series resistors are added to those bring-up-only signals at this stage.

### Rationale

- The probe-access concept was internal, accessed only by engineers with ESD precautions during
  development.
- Adding ESD protection to every bring-up-only signal adds cost, board space, and complexity before
  there is validated evidence that it is needed.
- Risk accepted for prototype: controlled lab environment, trained operators, no field exposure.

### Post-Prototype Action Required

- During first prototype test phase, evaluate signal integrity and ESD sensitivity on any temporary
  bring-up probe lines.
- If any such lines are exposed to field conditions (e.g., external test connectors), add series
  33Ω + TVS per line.
- Document findings and update this log with the final resolution.

---

## DEC-011 — All Power Rails on Power Module; 3V3_ENIG Serves Rotor Stack

- **Status:** ✅ RESOLVED
- **Date:** 2025
- **Category:** Electrical
- **Area:** Power Module islands, Controller Board routing, rotor stack power source

### Decision

All power rails are generated on the **Power Module**. The Controller Board's role is purely to **route** power rails onward to downstream boards — it does not generate any rails itself. The rotor
stack is powered by the existing **3V3_ENIG** rail (TPS75733KTTRG3 LDO, 3A). There is no separate Rotor Buck; the erroneous "3.3V/5A Rotor Buck" specification was a confusion with the 5V/5A CM5 rail and
has been removed.

### Rationale

- Centralising all power generation on the Power Module simplifies thermal management (all heat dissipation in one shielded enclosure with dedicated thermal zone).
- Reduces the risk of ground loops and cross-domain sequencing issues.
- The Controller Board as a routing layer keeps its design cleaner and easier to revise independently.
- 3V3_ENIG (3A) covers all 3.3V consumers: CPLDs, USB-JTAG, I2C logic, control signals, and the rotor stack.
- Settings Board RGB indicators are powered from 5V_MAIN via the Stator/Settings 6-pin harness; only
  their control logic remains on 3V3_ENIG.
- ROTOR_EN (CM5 GPIO 16) enables/disables the 3V3_ENIG LDO for sequenced rotor power-up — a control signal only.

### Architectural Rule (permanent)

> All power rails are generated on the Power Module. The Controller Board routes rails to downstream boards only. No buck converters, LDOs, or other power-generating components belong on the
> Controller Board.

### Impact

- `README.md`: Removed erroneous "Dedicated 3.3V/5A Buck" from Controller Board section; 3V3_ENIG correctly listed as Power Module output serving CPLDs, logic, and rotor stack.
- `Power_Module/Design_Spec.md`: 3V3_ENIG scope updated to include rotor stack; 3-island Power Plane retained.
- `Controller/Design_Spec.md`: ROTOR_EN clarified as LDO enable signal to Power Module.
- `Rotor/Design_Spec.md`: Power source updated from "Controller Board Island C" to "Power Module 3V3_ENIG rail".

### Previously Conflicting References (now corrected)

- `README.md` placed the Rotor Buck under the Controller Board section.
- `Rotor/Design_Spec.md` said "sourced from the Controller Board's Island C".

---

## DEC-012 — U4 TPS25750 Replaced with TPS25751DREFR (NRND Resolution)

- **Status:** ✅ RESOLVED
- **Date:** 2026-04-03
- **Category:** Electrical
- **Area:** Power Module U4, schematic, PCB footprint

### Decision

Replace **TPS25750** (NRND — Not Recommended for New Designs) with **TPS25751DREFR** (PD3.1 certified DRP controller, WQFN-38 6×4mm).

### Rationale

- PD emulation for U4 is required: the Raspberry Pi CM5 must negotiate a 5V/5A (25W) contract from the USB-C PD source to prevent the OS from issuing under-voltage warnings and throttling the system.
- The TPS25751D variant includes the integrated 20V/5A bi-directional power path and a 5V/3A source switch in one package — appropriate for DRP operation that can advertise and deliver the 5V/5A

  profile to the CM5.

- TPS25751 is USB-IF PD3.1 certified (TID#10306); TPS25750 was PD2.0 only and is NRND.
- STUSB4500 (U5) handles the USB-C sink path; TPS25751 (U4) handles the source/emulation path. These are separate and complementary roles.

### Impact

- **Package**: TPS25750 was QFN-28; TPS25751DREFR is WQFN-38 6×4mm. KiCad symbol and footprint to be created when schematic capture begins.
- Mouser: `595-TPS25751DREFR`; DigiKey: `296-TPS25751DREFRCT-ND`; JLCPCB: `C30169739`.

---

## DEC-013 — L3 EMI Inductor Changed to Bourns SRP1265A-100M

- **Status:** ✅ RESOLVED
- **Date:** 2026-04-03
- **Category:** Electrical
- **Area:** Power Module L3, PCB footprint

### Decision

Replace **Würth 7447789100** with **Bourns SRP1265A-100M** as L3 (EMI DM Pi-filter inductor).

### Rationale

- Würth 7447789100 is not available in any public distributor catalog (not found at DigiKey, Mouser, Farnell, or on the Würth public website). Sourcing without a Würth rep contact is not feasible.
- Bourns SRP1265A-100M is a direct functional equivalent: 10µH, **15.5A Isat** (exceeds 14.5A target with 21% headroom), DCR=16.5mΩ max (better than the original 20mΩ spec), shielded molded SMD.
- Widely stocked: Farnell ~2,741 pcs; Mouser (`652-SRP1265A-100M`); DigiKey (`SRP1265A-100MCT-ND`).

### Impact

- ⚠️ **Package footprint change**: SRP1265A-100M is 13.5×12.5×6.2mm vs 7447789100's 12.5×12.5×6.0mm. PCB land pattern for L3 must use the Bourns 13.5×12.5mm footprint. Clearance to adjacent

  components should be checked during layout.

---

## DEC-014 — Controller Board Uses ERF8 (Female) on Both BtB Connectors for Blind-Mate Assembly

- **Status:** ✅ RESOLVED
- **Date:** 2026-04-04
- **Category:** Electrical
- **Area:** Controller J1 (Link-Alpha), Controller J2 (Link-Beta), Consolidated BOM connector inventory

### Decision

Both BtB connectors on the Controller Board use the ERF8 female socket: J1 (Link-Alpha) uses **ERF8-040-05.0-S-DV-K-TR** and J2 (Link-Beta) uses **ERF8-020-05.0-S-DV-K-TR**.
The mating male plugs are fitted to the Power Module (J1, ERM8-040) and the Stator Board (J8, ERM8-020-05.0-S-DV-K-TR) respectively.

### Rationale

During mechanical assembly, the Controller Board slides into the enclosure and must simultaneously engage with two boards along its back edge
— the Power Module (J1) to one side and the Stator (J2) to the other.
Using female sockets on the Controller allows guided blind-mate engagement in a single insertion motion,
with the mating male pins on the peripheral boards providing positive alignment.
Placing male headers on the Controller would require both peripheral boards to be precisely pre-positioned before the Controller could be inserted,
significantly complicating assembly.

### Connector Assignment Summary

| Board | Connector | Gender | Part |
| :--- | :--- | :--- | :--- |
| Controller | J1 (Link-Alpha, from Power Module) | Female | ERF8-040-05.0-S-DV-K-TR |
| Controller | J2 (Link-Beta, to Stator Board) | Female | ERF8-020-05.0-S-DV-K-TR |
| Power Module | J1 (Link-Alpha plug) | Male | ERM8-040-05.0-S-DV-K-TR |
| Stator Board | J8 (Link-Beta plug) | Male | ERM8-020-05.0-S-DV-K-TR |

### Impact

- Controller BOM J2 updated from ERM8 (male) to ERF8 (female); JLCPCB C-number to be verified.
- Controller §2 narrative updated to reflect ERF8 on Link-Beta.
- No electrical impact — connector is signal-transparent; pin assignments unchanged.

---

## DEC-015 — LINK-BETA Connector Reduced from 80-pin to 40-pin (ERF8-020 / ERM8-020)

- **Status:** ✅ RESOLVED
- **Date:** 2026-04-04
- **Category:** Electrical
- **Area:** Controller Board (J2), Stator Board (J8), Consolidated BOM
- **Amended by:** DEC-036 (2026-04-18), DEC-037 (2026-04-18)

### Decision

The LINK-BETA Board-to-Board connector is reduced from 80-pin (ERF8-040 / ERM8-040) to **40-pin
(ERF8-020-05.0-S-DV-K-TR / ERM8-020-05.0-S-DV-K-TR)**. The table below records the original
post-reduction allocation; the current active allocation is defined by **DEC-037**.

| Pin | Signal | Direction | Notes |
| :--- | :--- | :--- | :--- |
| 1 | GND | — | JTAG leading shield |
| 2 | TCK | CTRL→Stator | JTAG clock |
| 3 | GND | — | TCK/TMS inter-pin shield |
| 4 | TMS | CTRL→Stator | JTAG mode select |
| 5 | GND | — | TMS/TDI inter-pin shield |
| 6 | TDI | CTRL→Stator | JTAG data in |
| 7 | GND | — | TDI/SPARE inter-pin shield |
| 8 | SPARE | — | Freed by DEC-031 (was SYS_RESET_N — migrated to I²C U7 GPA[7] @ 0x21) |
| 9 | GND | — | JTAG trailing shield |
| 10 | GND | — | Isolation moat pin 1 |
| 11 | GND | — | Isolation moat pin 2 |
| 12 | SPARE | — | Freed by DEC-031 (was ENC_IN[0] — migrated to I²C U6 @ 0x20) |
| 13 | SPARE | — | Freed by DEC-031 (was ENC_IN[1]) |
| 14 | SPARE | — | Freed by DEC-031 (was ENC_IN[2]) |
| 15 | SPARE | — | Freed by DEC-031 (was ENC_IN[3]) |
| 16 | SPARE | — | Freed by DEC-031 (was ENC_IN[4]) |
| 17 | SPARE | — | Freed by DEC-031 (was ENC_IN[5]) |
| 18 | GND | — | Inter-group shield |
| 19 | SPARE | — | Freed by DEC-031 (was ENC_OUT[0] — migrated to I²C U6 @ 0x20) |
| 20 | SPARE | — | Freed by DEC-031 (was ENC_OUT[1]) |
| 21 | SPARE | — | Freed by DEC-031 (was ENC_OUT[2]) |
| 22 | SPARE | — | Freed by DEC-031 (was ENC_OUT[3]) |
| 23 | SPARE | — | Freed by DEC-031 (was ENC_OUT[4]) |
| 24 | SPARE | — | Freed by DEC-031 (was ENC_OUT[5]) |
| 25 | GND | — | ENC_OUT / TTD_RETURN shield |
| 26 | TTD_RETURN | Stator→CTRL | JTAG TDO short-path return (bypasses rotor stack) |
| 27 | GND | — | TTD_RETURN shield |
| 28–35 | 3V3_ENIG | PM→Stator | Power pass-through from Link-Alpha; 8 pins × 0.5A = 4.0A |
| 36–40 | GND | — | Power return (5 pins) |

### Rationale

Logic boards downstream of the Stator (Encoder, Reflector, Extension) are 3V3-only — they require
no 5V_MAIN rail. Removing 5V_MAIN from LINK-BETA and rationalising the signal set results in exactly
40 signals. The JTAG block has 5 internal GND shield pins (self-shielded at low-moderate MHz), so only
a 2-pin GND moat is needed between JTAG and the data zone. 8 × 3V3_ENIG pins deliver 4.0A — adequate
for the worst-case 30-rotor stack (2.11 A per Power_Budgets.md). 5 GND return pins plus the 10 other GND pins throughout the
connector provide adequate return paths.

### Poka-Yoke Safety Note

The 80-pin LINK-ALPHA (ERF8-040) and 40-pin LINK-BETA (ERF8-020) on the Controller Board are
**physically incompatible** — the mating connectors cannot be inserted into the wrong socket. This
provides a mechanical safeguard against mismating during prototype bring-up.

### Alternatives Considered

Keeping 80-pin connector with unused pins. Rejected: unnecessary connector cost and PCB area; larger
connector on the Stator increases stack height with no benefit.

### Impact

- Controller J2: ERF8-040 → ERF8-020-05.0-S-DV-K-TR (female, 40-pin)
- Stator J8: ERM8-040 → ERM8-020-05.0-S-DV-K-TR (male, 40-pin)
- DEC-014 connector table updated (see cross-ref below).

### Cross-ref

DEC-014 (gender assignment rationale remains valid; part numbers updated). DEC-031
(pins 8, 12–17, and 19–24 freed — SYS_RESET_N and ENC_IN/OUT migrated to I²C).
DEC-036 (freed monitor block reallocated into grouped 5V_MAIN / 3V3_ENIG / GND rails).

---

## DEC-016 — JTAG Controlled Impedance and Series Termination

- **Status:** ✅ ADOPTED
- **Date:** 2026-04-05
- **Category:** Electrical
- **Area:** Controller Board, Stator Board, Encoder Board, Reflector Board (noted), Extension Board (noted)

### Decision

All JTAG signal traces on 4-layer and 6-layer PCBs are specified at **50 Ω controlled impedance**
(0.127 mm / 5 mil trace width on outer layers over a contiguous GND plane). Series termination
resistors are added at every cable-driving JTAG output using **75 Ω** (to match the ~100 Ω
impedance of alternating-GND IDC ribbon cable), and at every intra-board or BtB-driving JTAG output
using **33 Ω** (to match the 50 Ω PCB trace impedance).

Full signal-swing analysis confirms the destination CPLD receives full logic swing (3.3 V) in all
cases. The open-circuit reflection at the high-impedance CPLD input doubles the incoming wave back
to full voltage; the series resistor controls the return reflection, not the final voltage.

### Full analysis, all options considered, and trace width calculations

See `design/Electronics/Investigations/JTAG_Integrity.md`.

### Summary of additions per board

| Board | Refs | Value | Purpose |
| :--- | :--- | :--- | :--- |
| Controller | R4, R5, R6 | 33 Ω 0603 | ~~TCK / TMS / TDI series R after 74LVC2G125 buffer, before LINK-BETA~~ **Moved to JDB — see DEC-024** |
| Stator | R7–R9 | 75 Ω 0603 | TCK → J4 / J5 / J6 encoder port outputs |
| Stator | R10–R12 | 75 Ω 0603 | TMS → J4 / J5 / J6 encoder port outputs |
| Stator | R13–R15 | 75 Ω 0603 | TDI chain drive: Stator CPLD TDO→J4, J4 return→J5, J5 return→J6 |
| Encoder | R7 | 33 Ω 0402 | CPLD1 TDO → CPLD2 TDI (intra-board, match 50 Ω PCB trace) |
| Encoder | R8 | 75 Ω 0402 | CPLD2 TDO → J2 connector (ribbon cable drive back to Stator) |
| JDB | R6, R7, R8 | 33 Ω 0402 | TCK / TMS (after U5 buffer) / TDI series damping — before J2 JTAG header |

> **Update (detailed design):** U5 (SN74LVC2G125DCUR buffer) and series damping resistors relocated
> from Controller to JDB during detailed design. LINK-BETA is confirmed as a direct Board-to-Board
> connector (no cable), so 33 Ω series damping applies throughout (not 75 Ω cable-driving rule).
> Controller JTAG lines (TCK, TMS, TDI, TTD_RETURN, VREF) are pass-through — routed directly from
> JDB hat-header to LINK-BETA without active components. See DEC-024.

**Trace width rule added to all 4-layer and 6-layer boards:** 0.127 mm (5 mil) for all JTAG signal
traces on outer layers over a GND plane.

**2-layer boards (Reflector, Extension):** Controlled impedance not practical — 50 Ω would require
a 2.82 mm trace (see `design/Electronics/Investigations/JTAG_Integrity.md §4`). Series termination at cable-driving ends of adjacent
boards provides sufficient protection. Existing Reflector R1 (22 Ω) retained as end-of-chain damping.

> **Superseded (partial):** The Reflector and Extension 2-layer limitations above are superseded by
> DEC-017, which upgrades both boards to 4-Layer JLC04161H-7628. Both boards now have a solid L2 GND
> plane and route JTAG on L1 at 0.127 mm (50 Ω), consistent with all other 4-layer boards.

### Rationale

Achieving 100 Ω PCB traces (to perfectly match the IDC ribbon cable impedance) is physically
impossible on JLCPCB standard 4-layer/6-layer stackups — the required trace width is negative
(see calculation in `design/Electronics/Investigations/JTAG_Integrity.md §4`). The 50 Ω + 75 Ω hybrid approach provides the best
achievable impedance match to the cable while remaining within manufacturing design rules.

### Alternatives Considered

- **No termination (Option A):** Rejected — multiple re-reflections at 10 MHz risk false TCK edges.
- **50 Ω PCB + 33 Ω series R (Option B):** Acceptable but leaves 33% reflection at PCB-to-cable
  transition unabsorbed.
- **100 Ω PCB + 82 Ω series R (Option C, ideal):** Rejected — not achievable on standard stackup.

### Cost Impact

Additional BOM cost per full system < £0.05. No JLCPCB impedance certification required for
prototype; trace widths self-calculated and within ±10% of target. See `design/Electronics/Investigations/JTAG_Integrity.md §9`.

---

## DEC-017 — Minimum 4-Layer Stackup for All Non-Controller Boards

- **Status:** ✅ ADOPTED
- **Date:** 2026-04-05
- **Category:** Electrical
- **Area:** Reflector Board, Extension Board (all other boards already compliant)

### Decision

All PCBs in the Enigma-NG system shall use a minimum of **4-layer stackup** (JLCPCB
JLC04161H-7628). The Controller Board and the Power Module Board are the only exceptions
and retain their 6-layer JLC06161H-2116 stackup: the Controller for high-speed 5 Gbps
differential pair requirements, and the Power Module for high-current power delivery.

### Standard 4-layer layer mapping for all non-Controller boards

| Layer | Function |
| :--- | :--- |
| L1 | Signal (JTAG, data routing) — top |
| L2 | GND plane — solid contiguous copper |
| L3 | 3V3_ENIG power plane |
| L4 | Signal (data routing, branding data plate) — bottom |

> **Exception — JTAG Daughterboard:** The JDB uses an inverted stackup: L1=GND plane + SMT
> component pads (component side, faces Controller), L2=signal traces, L3=power pours,
> L4=GND shield (exterior face). This inversion places components on the face that mates
> with the Controller Board hat-headers, consistent with single-side JLCPCB assembly.
> See `JTAG_Daughterboard/Design_Spec.md §4`.

### Boards affected (updated)

| Board | Previous | New |
| :--- | :--- | :--- |
| Reflector | 2-Layer 1.6mm FR4 / 1oz | 4-Layer JLC04161H-7628 / 2oz |
| Extension | Layer count unspecified | 4-Layer JLC04161H-7628 / 2oz |

### Boards already compliant (no change)

| Board | Stackup | Notes |
| :--- | :--- | :--- |
| Stator | 4-Layer JLC04161H-7628 | ✅ Unchanged |
| Encoder | 4-Layer JLC04161H-7628 | ✅ Unchanged |
| Rotor | 4-Layer JLC04161H-7628 | ✅ Unchanged |
| Controller | 6-Layer JLC06161H-2116 | ✅ Exception — high-speed stackup retained |
| Power Module | 6-Layer JLC06161H-2116 | ✅ Exception — high-current power delivery stackup retained |

### Impact

The "2-layer uncontrolled impedance" notes for Reflector and Extension in DEC-016 are superseded.
Both boards now have a solid L2 GND plane and can route JTAG on L1 at 0.127 mm (50 Ω controlled
impedance), consistent with all other 4-layer boards. `design/Electronics/Investigations/JTAG_Integrity.md §3.1`, `§3.3` (now
historical), and `§8` trace table have been updated accordingly.

### Rationale

1. **Uniform stackup:** Consistent JLC04161H-7628 across all non-Controller boards eliminates
   stackup-dependent trace impedance variation, reducing signal behaviour differences between boards.
2. **Solid GND on every board:** All boards now have a contiguous L2 GND plane, enabling 50 Ω
   controlled impedance JTAG routing across the entire system.
3. **EMC/EMI improvement:** Solid GND and power planes on all boards reduce radiated emissions and
   improve common-mode noise rejection across the rotor stack and encoder cabling.
4. **Manufacturing speed:** JLC04161H-7628 is JLCPCB's most common 4-layer stackup, with higher
   stock availability and faster turnaround than 2-layer special orders or less common stackups.
5. **Cost:** Marginal price difference between 2-layer and 4-layer at JLCPCB prototype quantities;
   outweighed by signal integrity and EMC benefits.

### Alternatives Considered

- **Retain 2-layer Reflector/Extension:** Rejected — inconsistent stackup creates impedance
  discontinuities in the JTAG chain and leaves an uncontrolled segment at the reflector end.
- **Use different 4-layer stackup per board:** Rejected — non-uniform dielectric parameters would
  require separate trace width calculations per board and add unnecessary design complexity.

---

## DEC-018 — Connector Pinout Ownership Model

- **Status:** Adopted
- **Date:** 2026-04-05
- **Category:** Electrical
- **Area:** All Boards — Documentation Architecture

### Decision

Each multi-board connector interface shall have a single **Definition Owner** — the board whose
`Board_Layout.md` (or `Design_Spec.md` where no Board_Layout exists) contains the authoritative
pin-by-pin table for that interface. All other boards that mate with that connector must
**not** duplicate the pin table; instead they include a short cross-reference note of the form:

> **Connector Definition Owner:** `[OwnerBoard]/Board_Layout.md — [Section]`. This board uses the
> mating connector. See BOM for part number.

This rule prevents the class of drift errors where two boards define the same connector differently
(e.g. Pin 2 = GND on one board, SYS_RESET_N on another). When a conflict is found, the owner's
definition is authoritative.

### Ownership Register

| Interface | Connector(s) | Definition Owner | Authoritative Section |
| :--- | :--- | :--- | :--- |
| **LINK-ALPHA** | PM J1 ↔ Controller J1 (80-pin ERM8/ERF8) | **Power Module** | `Power_Module/Board_Layout.md — LINK-ALPHA` |
| **LINK-BETA** | Controller J2 ↔ Stator J8 (40-pin ERM8/ERF8) | **Controller** | `Controller/Board_Layout.md — LINK-BETA` |
| **Reflector/Extension Link** | Stator J10 ↔ Extension J7/J8 ↔ Reflector J4 (16-pin 2×8) | **Stator** | `Stator/Board_Layout.md — J10` |
| **Encoder Ports** | Stator J4/J5/J6/J7/J8/J9 ↔ Encoder J2 (20-pin 2×10) | **Stator** | `Stator/Board_Layout.md — J4–J9` |
| **Rotor Interface** | Stator J1–J3 ↔ Rotor 1 → … → Rotor 30 → Reflector J1–J3 (serial chain; Extension J1–J6 at group boundaries) | **Rotor** | `Rotor/Design_Spec.md §3.4` |
| **JTAG Daughterboard headers** | JDB J1 (USB 5-pin) + J2 (JTAG 10-pin) | **JTAG Daughterboard** | `JTAG_Daughterboard/Board_Layout.md` |

### Rationale

- **LINK-ALPHA → Power Module:** The Power Module is the upstream power provider; it defines what
  rails and signals it places on the cable. The Controller is the downstream consumer.
- **LINK-BETA → Controller:** The Controller is the JTAG chain master. It originates TCK, TMS, TDI,
  SYS_RESET_N, and the ENC data bus. The Stator is the passive backplane receiver.
- **Reflector/Extension Link → Stator:** The Stator is the signal origin for all ENC data, power,
  and TTD_RETURN carried on this cable. Extension and Reflector are passive pass-throughs or endpoints.
- **Encoder Ports → Stator:** The Stator drives all three encoder cables and has the complete chain
  routing logic for TDI/TDO sequencing across J4/J5/J6. The Encoder boards are the downstream receivers.
- **Rotor Interface → Rotor:** The Rotor defines its own physical interface — both the connector
  type (mechanical) and the signal mapping. Stator, Extension, and Reflector must comply with the
  Rotor's mechanical interface, not the other way round.
- **JTAG Daughterboard → itself:** Self-contained module with no cross-board mating conflicts.

### Alternatives Considered

- **Central `Interfaces.md` document:** Rejected — separates pin definitions from the board they belong
  to, making it harder to keep in sync during incremental design changes. Per-board ownership with
  cross-references is more maintainable.
- **Both sides document the full table:** Rejected — this is the exact pattern that caused the REF-03
  Pin 2 conflict and the REF-01 16/20-pin mismatch found in the April 2026 deep-dive review.

---

## DEC-019 — PoE Transformer Topology: ACF (Option A) Selected

- **Status:** ✅ Adopted
- **Date:** 2026-04-05
- **Category:** Electrical
- **Area:** Power Module — T2 transformer, TPS23730 operating mode, input EMI filter

### Decision

The Power Module retains the **Active Clamp Flyback (ACF)** topology with the **Coilcraft POE600F-12LD**
transformer. The TPS23730 operates in ACF mode, driving an external active clamp MOSFET complementary
to the primary switch. The Coilcraft transformer is procured order-direct from `coilcraft.com` and
supplied to JLCPCB as a consignment part.

No change is made to the T2 transformer, the TPS23730 mode configuration, or the active clamp circuit.

**Full investigation detail:** `design/Electronics/Investigations/PoE_Investigation.md`

### Rationale

A thorough search confirmed that **no ACF PoE isolation transformer for 60W / 36–57V input is stocked
by any mainstream authorised distributor** (DigiKey, Mouser, Farnell, Arrow). The Coilcraft POE600F
family was co-developed with TI specifically for the TPS23730 reference design; no competing catalogue
part exists.

The only standard-distributor alternative identified was the **Bourns PDC060-FD20A12S** — a standard
flyback transformer available from DigiKey. Switching to this part (Option B) would have required:

- Disabling TPS23730 `ACF_GD` (ACF gate drive pin)
- Removing the active clamp MOSFET and capacitor
- Adding an RCD clamp (3 SMD components)
- Verifying PSR auxiliary winding compatibility (unconfirmed)

After detailed EMI/EMC analysis, Option B was rejected on technical grounds. Key findings:

| Criterion | Option A (ACF) | Option B (Flyback) |
| :--- | :--- | :--- |
| Primary switching | ZVS — no hard dV/dt event | Hard switching — fast dV/dt |
| Drain spike at turn-off | None — energy recycled by clamp | Present — RCD clamp clips but does not eliminate |
| CM/DM conducted EMI | Low | 15–25 dB higher before input filter |
| Input EMI filter size | Smaller / fewer components | Larger / more complex |
| CISPR 32 Class B margin | Comfortable | Tight — may require design iteration |
| Efficiency | 88–92% | 85–90% |
| Extra dissipation | — | ~1–2W at full load |
| PSR aux winding verified | ✅ TI reference design | ⚠️ Unverified for Bourns PDC060 |

The Coilcraft direct-order model is accepted as a specialist procurement path, consistent with
industry practice for catalogue magnetics.

### Alternatives Considered

- **Bourns PDC060-FD20A12S (Option B — flyback PSR):** Rejected — hard-switching topology causes
  significantly higher conducted and radiated EMI, requires a larger input EMI filter, does not
  eliminate procurement complexity (shifts effort from transformer sourcing to filter design),
  and adds ~1–2W thermal load to an already thermally constrained module.
- **Würth WE-FB range:** Rejected — entire range has a maximum input voltage of 36V (insufficient
  for PoE 36–57V input) and is keyed to Linear Technology LT-series controllers.
- **Change PoE controller ecosystem:** Not evaluated — would constitute a major redesign and is
  out of scope.

---

## DEC-020 — GND_CHASSIS Rib Clearway ENIG Bond

- **Status:** Accepted — 2026-04-08
- **Date:** 2026-04-08
- **Category:** Electrical
- **Area:** Power Module — Supercap Block Assembly & Board Layout
- **References:** QUE-001, Certification_Evidence.md §2.2

### Decision

The 3.0mm rib clearway gaps between supercap cells shall have:

1. **Exposed ENIG strip (L1):** Solder mask opened in the rib clearway gap on the top copper layer (L1),
   connected to the GND_CHASSIS net. Minimum strip width 1.5mm, running the full depth of the rib contact zone.
   The aluminium enclosure rib makes direct electrical contact with the PCB GND_CHASSIS copper, providing a
   distributed HF chassis ground bond at the supercap block location.

2. **Polyimide (Kapton) tape on supercap bodies:** Each supercap cell shall be wrapped with a minimum of
   one layer of 2-mil (50µm) polyimide tape prior to installation, to electrically insulate the cell body
   from the aluminium compression ribs and prevent short circuits.

3. **Conductive elastomer gasket strip:** A self-adhesive conductive elastomer or conductive foam gasket strip
   (≤3mm wide, full rib contact depth) shall be applied to the rib face or PCB contact zone to accommodate
   manufacturing tolerances and ensure positive, reliable electrical contact under compression.
   Part to be selected at mechanical design phase when rib geometry is confirmed.

### Rationale

The combined structure — aluminium Can lid, compression ribs, conductive gasket, PCB ENIG strip, and
GND_CHASSIS copper pour — forms a near-complete Faraday cage around the supercap block, improving
shielding of the high-capacitance energy storage element from the rest of the board.

### Compatibility with single-point GND_CHASSIS bond rule

The single-point rule governs signal GND → GND_CHASSIS crossings. Rib contact bonds are
enclosure-to-GND_CHASSIS connections — both within the chassis domain — and do not create additional
signal-to-chassis bonds. The rule is maintained.

### Other boards

Deferred pending mechanical design documentation. Controller Board Mechanical_Design.md §3 notes the
prototype uses a 3D-printed chassis (no conductive rib contact); this decision will be revisited when
metal chassis dimensions are finalised. Stator/Encoder/Rotor mechanical designs are not yet written.

---

## DEC-021 — Supercapacitor Bank Upgrade: 2×2 2S2P → 2×3 2S3P

- **Status:** Superseded by DEC-029 (arrangement 2S3P retained; cell capacitance updated 22F → 25F Abracon)
- **Date:** 2026-04-08
- **Category:** Electrical
- **Area:** Power Module — Supercap Bank, Board Layout, Hold-up Specification
- **References:** DR-PM-07, DR-PM-09, DEC-020

### Decision

The supercapacitor bank is upgraded from a 2×2 (4-cell, 2S2P) to a **2×3 (6-cell, 2S3P)** arrangement,
with the inter-cell air gap increased from 2.0mm to **3.0mm**.

| Parameter | Previous | New |
| :--- | :--- | :--- |
| Cell count | 4 (C_SC1–4) | 6 (C_SC1–6) |
| Arrangement | 2×2 | 2×3 |
| Configuration | 2S2P | 2S3P |
| Inter-cell gap | 2.0mm | 3.0mm |
| Cell pitch | 14mm | 15mm |
| Block footprint | 28mm × 28mm | 30mm × 45mm |
| Shadow zone | 32mm × 32mm | 34mm × 49mm |
| Effective capacitance | 22F at 5.4V | 33F at 5.4V |
| Hold-up energy | 72.4J | 108.6J |
| Hold-up duration @ 5W | ≥14.5s | ≥21.7s |
| Charge time (depleted) | ~2 min | ~3 min |

### Rationale

- **50% more hold-up:** 33F vs 22F provides ≥21.7 seconds at 5W — a more comfortable shutdown window
  and headroom for higher CM5 load profiles at prototype bring-up.
- **LTC3350 compatibility:** No IC change required. LTC3350 is configured for 2 cells in series;
  each series position now has 3×22F in parallel (66F per position). CELLS register unchanged.
  RICHARGE (0.5A charge current limit) unchanged; charge time increases ~3 minutes from depleted.
- **Wider gap (3mm):** The increased inter-cell gap from 2.0mm to 3.0mm provides adequate clearance
  for the 2-mil Kapton tape wrap (DEC-020), the conductive elastomer gasket strip, and the aluminium
  enclosure compression ribs, while maintaining margin for manufacturing tolerances.
- **Board space:** The Power Module board dimensions are not yet fixed; the design is being built
  around this component block. The increased footprint (30mm × 45mm vs 28mm × 28mm) is accepted.

> **Post-decision update (2026-04-08, checkpoint 025):** The 22F generic cells specified above
> were subsequently replaced with **Abracon ADCR-T02R7SA256MB (25F/2.7V)** when a verified in-stock
> THT radial supercap was sourced. The 2S3P arrangement and all mechanical dimensions are unchanged.
> Effective capacitance increases from 33F to **37.5F**; hold-up increases from 21.7 s to **≥24.8 s**.
> The values **22F / 33F / 21.7 s** are historical and must not be restored.

---

## DEC-022 — JDB FT232H Clock Source: Dedicated 12MHz SMD Crystal Selected

- **Status:** Obsolete — superseded by DEC-037
- **Date:** 2026-04-06
- **Category:** Electrical
- **Area:** JTAG Daughterboard — Clock Source (FT232H)

### Decision

Dedicated 12MHz SMD passive crystal (Y1) on the JDB PCB. CM5 GPCLK0 option rejected.

### Context

During JDB detailed design review, two issues were identified:

1. The original design incorrectly specified a **24MHz HC-49 through-hole crystal**. The FT232H datasheet requires a **12MHz**
   reference — its internal PLL multiplies 12MHz × 40 to generate 480MHz for USB Hi-Speed operation. 24MHz is outside specification.
2. An alternative was considered: routing a clock from the **CM5 GPCLK0 output (GPIO4)** to the FT232H OSCI pin instead of a dedicated on-board crystal.

### Options Considered

| Option | Description | Verdict |
| :--- | :--- | :--- |
| A | CM5 GPCLK0 (GPIO4) routed through Controller hat-header to FT232H OSCI | **Rejected** |
| B | Dedicated 12MHz passive SMD crystal (Y1) on JDB PCB | **Selected** |

**Option A — Rejected reasons:**

- Signal path: CM5 GPIO4 → Controller board → hat-header pin → JDB OSCI is long and noise-prone
- GPIO clock jitter from BCM is unsuitable as a USB PLL reference clock
- Creates a CM5 boot-order dependency — FT232H cannot enumerate on USB until CM5 configures GPCLK0
- Adds routing and firmware complexity with no benefit over a $0.07 crystal

**Option B — Selected:**

- Standard FTDI reference design approach; clean stable clock source
- No boot dependency; FT232H enumerates immediately on USB connect
- Component: **YXC X322512MSB4SI** (JLCPCB C9002), SMD3225-4P, 12MHz, 20pF, ±20ppm, Basic part
- Crystal load capacitors: C10–C11 = 33pF C0G 0402 (sets 20pF load capacitance)

### Impact

- `design/Electronics/JTAG_Daughterboard/Design_Spec.md`: Y1 corrected to 12MHz SMD3225-4P (C9002); C10–C11 added; text references updated.

---

## DEC-023 — JDB GND_CHASSIS Omitted; Mounting Holes Tied to GND

- **Status:** Decided
- **Date:** 2026-04-06
- **Category:** Electrical
- **Area:** JTAG Daughterboard — Grounding & EMC

### Decision

The JTAG Daughterboard (JDB) does **not** implement a `GND_CHASSIS` net. Mounting holes are included
for mechanical stability via conductive standoffs to the Controller board; the copper pours around
those mounting holes are tied to **GND** (circuit return). No dedicated chassis bond pad, stitching
via, or `GND_CHASSIS` net is present on the JDB.

> Cross-reference: DEC-039 keeps the single Power Module bond rule but now makes this JDB treatment
> the generic exception for non-chassis-connected daughterboards.

### Rationale

`GND_CHASSIS` exists to bond a PCB to the metal enclosure for EMC shielding, ESD protection, and safety earth. None of those functions apply to the JDB because:

1. **No chassis surface** — the JDB is an internal daughterboard that floats above the Controller
   board on hat-header pins and conductive standoffs. It has no metal enclosure surface it can
   directly bond to.
2. **EMC envelope already provided** — the Controller board beneath it carries a correctly implemented `GND_CHASSIS` net bonded to the system enclosure. The JDB sits entirely within that envelope.
3. **No external connections** — the JDB has no cables or connectors that exit the enclosure, so there are no ESD entry points that would require chassis bonding at the JDB level.
4. **Low-EMI device** — the FT232H operates at USB 2.0 speeds on an internal point-to-point link. It generates no significant conducted or radiated emissions that would require additional chassis shielding.
5. **Daisy-chaining adds no value** — connecting JDB `GND_CHASSIS` via standoffs to Controller
   `GND_CHASSIS` would create an additional path to chassis earth but no new bond point, adding
   PCB complexity for zero measurable EMC benefit.

### Implementation

- Include **mounting holes** on the JDB for mechanical stability.
- Standoffs are conductive (metal); this incidentally bonds the JDB mounting hole copper pours to the Controller board mechanically.
- Mounting hole copper pours connect to **GND** (circuit return) — not to a separate `GND_CHASSIS` net.
- This is consistent with standard practice for small internal sub-modules (e.g. Arduino shields, FPGA daughter cards).

### Alternatives Considered

- **Standoff bonding to Controller GND_CHASSIS:** Technically implementable but adds a separate net, a copper pour, and design rules for no measurable EMC gain on a low-EMI internal board. Rejected.
- **No mounting holes at all:** Rejected — mechanical retention via standoffs is required to prevent the board from flexing on the hat-headers during connector insertion/removal.

---

## DEC-024 — JDB is Complete JTAG Master; Controller JTAG Lines Are Pass-Through

- **Status:** Decided
- **Date:** 2026-04-06
- **Category:** Electrical
- **Area:** JTAG Architecture — Controller and JTAG Daughterboard

### Decision

The JTAG Daughterboard (JDB) is the complete JTAG master. The SN74LVC2G125DCUR dual-channel
buffer (U5) for TCK and TMS, and all 33 Ω series damping resistors (R6 TCK after U5, R7 TMS after
U5, R8 TDI direct from FT232H) are located on the JDB, before the J2 JTAG header. The Controller
board routes JTAG lines (TCK, TMS, TDI, TTD_RETURN, VREF) as pass-through from the JDB hat-header
to the LINK-BETA BtB connector without any active components.

LINK-BETA is a direct Board-to-Board connector (no cable). Therefore 33 Ω series damping (matched
to 50 Ω PCB trace impedance) applies throughout — not the 75 Ω cable-driving resistors specified
for ribbon cable connections. See DEC-016 for the full 75 Ω / 33 Ω rationale.

### Rationale

- **Simpler Controller BOM:** Removing U5, R4, R5, R6 from the Controller reduces complexity and
  potential assembly errors on the main board.
- **Cohesive JTAG subsystem:** All JTAG active components and termination are co-located on the JDB,
  which is the natural owner of the JTAG function.
- **BtB confirmation:** LINK-BETA is a Samtec ERF8-020 / ERM8-020 direct board-to-board stack (no
  ribbon cable). The 33 Ω source termination after U5 is the correct value for 50 Ω PCB traces.

### Impact

- `Controller/Design_Spec.md`: U5 removed from BOM; R4, R5, R6 removed; §3 updated to reflect
  pass-through routing; DR-CTL-05 updated; FR-CTL-04 reference to U5 removed.
- `JTAG_Daughterboard/Design_Spec.md`: U5 added to BOM; R6, R7, R8 (33 Ω 0402) added.
- `Electronics/Consolidated_BOM.md`: SN74LVC2G125DCUR moved from CTL column to JDB column;
  33 Ω 0402 count increased in JDB; 33 Ω 0603 row removed from CTL.
- `Electronics/Investigations/JTAG_Integrity.md`: §7.4 and §8 updated to reflect JDB location.
- `Design_Log.md DEC-016`: Update note added.

---

## DEC-025 — CM5 Shutdown Mechanism: Hardware-Driven; LTC3350 Software Support Deferred

- **Status:** Deferred — Software PoC Stage
- **Date:** 2026-04-09
- **Category:** Software
- **Area:** Software / Linux OS — CM5 Power Management Shutdown Path

### Decision

The final implementation of the CM5 graceful shutdown mechanism is **hardware-driven** via the
LTC3350 `/INTB` -> MIC1555 U15 -> Q5 BSS138 -> `PWR_BUT` one-shot path. Any LTC3350 software
support is deferred to the **Software PoC stage**, pending hardware availability for integration
testing, and is limited to I2C telemetry / LED-state handling rather than a dedicated interrupt pin.

The PWR_GD GPIO (GPIO 27, MCP121T-450E output) is rail-health telemetry only and does NOT trigger shutdown. It is a CM5 input that reads HIGH while 5V_MAIN ≥ 4.50V.

### Rationale

- The shutdown path is already covered by hardware, so no Linux interrupt path or device-tree
  mapping is required for safe power-off behaviour.
- Any future software support can read LTC3350 status over I2C without consuming another
  dedicated CM5 GPIO.
- Driver or service development still requires the physical hardware to be available for testing
  and validation.
- The system is designed for operational sessions of 15–30 minutes or longer. The hold-up window
  (≥33.5 s) is a generous safety margin; an unplanned shutdown from a fully-charged state is expected
  to be harmless. Deferring the driver to the PoC stage does not create a risk for hardware bring-up.
- Placeholder notes in design/Software/Linux_OS/Power_Management.md document the intended
  telemetry behaviour for reference; they are not a binding software specification.

### Impact

- design/Software/Linux_OS/Power_Management.md keeps the deferred LTC3350 telemetry notes but
  removes any requirement for a dedicated `/INTB` GPIO or device-tree interrupt mapping.
- The active hardware protection path is the LTC3350 /INTB → MIC1555 U15 → Q5 BSS138 →
  PWR_BUT one-shot circuit (3.01 s LOW pulse), which requires no software driver.

---

## DEC-026 — Rotor Position Encoder: AS5600 Replaced with Single-Track Capacitive Encoder

> ⚠️ Partially superseded by DEC-028 for dual-track N=64 architecture, Ø92mm PCB diameter, and aluminium shroud milled slots. Retained for historical context.

- **Status:** Accepted
- **Date:** 2026-04-12
- **Category:** Hardware
- **Area:** Rotor Board — Position Sensing (§2.1)

### Decision

The AMS AS5600 magnetic encoder (originally specified in DR-ROT-03) is replaced with a
**single-track absolute capacitive encoder** implemented entirely on the rotor PCB. The rotating
shroud flanges carry milled aluminium slots (air gap = low capacitance); K capacitive sensor pads on the PCB read the track
as a K-bit code. A combinational lookup table in the CPLD VHDL maps the raw sensor code to a
binary rotor position (0 to N−1). The SW1 modulo-N adder (ring setting) operates on the decoded
binary value. No external adder hardware is required — the decode and add are pure CPLD logic.

Three **Texas Instruments FDC2114RGHR** footprints are defined across the split rotor pair;
each rotor variant populates two of them:

- U2 (address 0x2A): Track A — bits[5:3] (N=64) or STGC bits[3:0] (N=26).
- U3 (address 0x2B): Board A STGC bit[4] (N=26 only). NOT POPULATED for N=64.
- U4 (address 0x2B): Track B — bits[2:0] (N=64 only). NOT POPULATED for N=26.
- CPLD implements I²C master to read pad states.

#### Track patterns (verified — all N codes unique)

- **26-char (K=5, N=26):** `00000100011001010011101111`
  Sensors at 0°, 13.846°, 27.692°, 41.538°, 55.385° from reference; arc/segment ≈ 10.63mm at r=44mm.
  Invalid codes (between-character / jam): 11, 13, 21, 22, 26, 31.
- **64-char (K=6, N=64):** Replaced by dual-track 3+3 reflected binary Gray code — see `Rotor_64_Char_Design.md §7` and DEC-028.
  Sensors at 0°, 5.625°, 11.25°, 16.875°, 22.5°, 28.125° from reference; arc/segment ≈ 4.32mm at r=44mm.
  All 64 six-bit codes are valid (standard 6-bit reflected binary Gray code; XOR-chain decode; no invalid-code jam detection required).

PCB outer diameter Ø92mm (inside Ø100mm aluminium shroud) — per DEC-028

### Rationale

- **AS5600 incompatible with single-track Gray code intent:** AS5600 is a single-magnet absolute
  angle sensor — it requires a single magnet on the rotating part and returns a 12-bit angle value.
  It does not implement Gray code sensing and was architecturally inconsistent with the original
  design intent stated in §1 ("single-track grey encoder").
- **No magnet pocket on shroud:** The AS5600 requires a diametrically magnetised magnet (~6mm dia)
  embedded in or attached to the rotating shroud, adding manufacturing complexity. The capacitive
  approach requires only milled aluminium slot patterns on the rotating shroud — no embedded components.
- **All sensing electronics on PCB:** Capacitive pads and FDC2114 ICs are standard PCB components.
  The shroud is a passive mechanical part.
- **Reliable at slow rotation rates:** The rotors step at human-typing speed (≤10 char/s). The
  FDC2114 conversion time (~1ms/channel at default rate) is well within the inter-step interval.
- **STGC lookup table consistent across variants:** Both 26-char and 64-char rotors use the
  identical CPLD decode mechanism; only table contents and modulus differ. No firmware
  architecture difference between variants.

### Impact

- `design/Electronics/Rotor/Design_Spec.md`: FR-ROT-02, FR-ROT-08, DR-ROT-03, DR-ROT-09, §1,
  §2.1 (full rewrite), §3.2 I²C note, BOM U2 → FDC2114RGHR, U3 added.
- `design/Electronics/Rotor/Rotor_26_Char_Design.md`: §5 ring setting updated; §6 added
  (geometry, track pattern, STGC→position lookup table).
- `design/Electronics/Rotor/Rotor_64_Char_Design.md`: §5 ring setting updated; §7 added
  (geometry, track pattern, STGC→position lookup table).
- `design/Electronics/Rotor/Board_Layout.md`: ASCII diagram updated; PCB Ø92mm (per DEC-028).
- `design/Electronics/Consolidated_BOM.md`: AS5600 row replaced with 2× FDC2114RGHR per rotor
  (60 units total across 30 rotors).
- `design/Electronics/Reflector/STGC_Generator.py`: Original script location noted — should be
  relocated to `design/Electronics/Rotor/` in a future tidy-up commit.

---

## DEC-027 — Rotor Position Readback via JTAG Virtual JTAG (USER0 UDR)

- **Status:** Accepted
- **Date:** 2026-04-12
- **Category:** Hardware / Firmware
- **Area:** Rotor Board CPLD — JTAG Interface; GUI App position display

### Decision

The CPLD on each rotor must expose the **effective rotor position** (STGC-decoded position +
SW1 ring offset, mod N) via **Intel Virtual JTAG** (Altera `VIRTUAL_JTAG` megafunction,
USER0 instruction) over the existing JTAG serial chain. This allows the CM5/JDB to read back
all 30 rotor positions in a single JTAG scan pass without consuming any additional PCB pins or
signal routing.

The effective position register is 6 bits wide (covers both variants; 26-char variant uses
bits [4:0], bit [5] = 0). The CPLD VHDL must instantiate the `VIRTUAL_JTAG` megafunction and
connect the effective position register to the user data register (UDR). Cipher substitution
operates continuously and independently of JTAG state.

### Rationale

- **Standard IEEE 1149.1 BSCAN cannot access internal registers:** Boundary scan (EXTEST/SAMPLE)
  captures I/O pin states only. The effective position is an internal CPLD register result and
  would require dedicated output pins to be visible via standard BSCAN.
- **Virtual JTAG avoids pin consumption:** The existing JTAG chain (TCK, TMS, TDI, TDO/TTD)
  is already routed through all 30 rotors. No additional pins, traces, or connectors are needed.
- **FT232H on JDB supports arbitrary JTAG instructions:** The JDB FT232H (in MPSSE mode) can
  issue the USER0 JTAG instruction to any device in the chain and clock out the UDR contents.
  The CM5 software can therefore poll all 30 positions by iterating through the chain.
- **GUI App feedback requires position data:** The GUI App Design_Spec requires real-time display
  of rotor positions. Virtual JTAG is the only defined data path from rotor CPLDs to the CM5 for
  this purpose — no I²C, SPI, or dedicated signal lines exist between the rotors and the CM5.
- **Non-intrusive to cipher operation:** The `VIRTUAL_JTAG` megafunction is fully synchronous
  with the JTAG clock domain and does not gate or interrupt the cipher substitution logic running
  on the CPLD system clock.

### Impact

- `design/Electronics/Rotor/Design_Spec.md`: FR-ROT-09 to be added (CPLD exposes effective
  position via JTAG USER0 UDR; 6-bit register; readable without interrupting cipher function).
  Note to be added in §2.2 or §3.3 cross-referencing Virtual JTAG and GUI App.
- `design/Software/GUI_App/Design_Spec.md`: Cross-reference to DEC-027 and JTAG readback path
  to be added when GUI App position-display feature is specified.
- CPLD VHDL (future): Must instantiate `VIRTUAL_JTAG` megafunction and connect effective
  position register. Scan sequence: JDB issues USER0; shifts 6-bit UDR from each of 30 rotors
  serially (180 bits total per full scan).
- `design/Electronics/JTAG_Daughterboard/Design_Spec.md`: FT232H MPSSE mode already specified;
  no hardware change required. Software driver must add USER0 scan sequence.

---

## DEC-028 — Split dual-board rotor architecture

- **Status:** Accepted
- **Date:** 2026-04-14
- **Category:** Hardware
- **Area:** Rotor Board — Physical Architecture; PCB Assembly; Position Encoder

### Decision

The rotor is split into two circular PCBs (Board A input side, Board B output side), each
Ø92mm, connected by four single-row 2.54mm THT headers (H_SW3 1×7, H_PWR 1×5, H_JTAG 1×5,
H_SENS 1×5; 22 pins total; mixed gender for physical keying). This resolves the
JLCPCB single-side SMT assembly constraint and simultaneously defines the rotor physical
thickness (~15mm with an 11.8mm board gap). Board A carries the CPLD (U1 EPM570T100I5N),
FDC2114 U2 (Track A encoder, bits[5:3] for N=64 or all 5 sensors for N=26), SW1 (ring
setting DIP), SW2 (forward map select DIP), and J1–J3 (ERM8 male, input side). Board B
carries FDC2114 U3 (Track B, bits[2:0], N=64 only — not populated for N=26), SW3 (return
map select DIP), and J4–J6 (ERF8 female, output side). These internal headers are manually
assembled post-JLCPCB SMT pick-and-place.

The aluminium shroud (Ø100mm outer, 4mm radial wall → Ø92mm inner) floats electrically,
retained by rolling-pin style cylindrical bearings with ceramic or nylon rolling elements for
electrical isolation. Gray code position slots are milled into the inner faces of the shroud
flanges (dish side for Track A / Board A; cover side for Track B / Board B). Bare copper
electrode pads on the PCB flat face at r≈44mm sense the pattern capacitively via FDC2114.

For N=64 the encoder is a dual-track 3+3 bit standard reflected Gray code (6-bit), giving
zero multi-bit transitions including wrap-around (position 63→0). The CPLD decodes via XOR
chain (G2B). For N=26 all 5 STGC sensor electrodes remain on Board A; U4 on Board B is not
populated.

### Rationale

- JLCPCB only performs SMT assembly on one side per PCB; splitting the board places all SMT
  components on the outward-facing side of each board, making both boards fully JLCPCB
  assemblable without manual rework of back-side SMT.
- The ~15mm rotor thickness matches original Enigma rotor proportions.
- The split enables a dual-track capacitive encoder (3+3 bits), achieving a perfect 6-bit
  reflected Gray code for N=64 with zero multi-bit transitions at any rotor position including
  the 63→0 wrap. This replaces the de Bruijn STGC approach (which required a lookup table and
  had no wrap-around guarantee).
- The aluminium shroud is passive: no conductive ink, no embedded magnets. Gray code slots are
  milled CNC features on a standard turned-aluminium part. Bearing isolation keeps the shroud
  electrically floating, preventing ground loops and capacitive coupling errors.

### Alternatives Considered

- **Single-board with back-side hand-soldering:** rejected — complex, unreliable, not
  consistent with high-volume JLCPCB assembly.
- **Magnetic encoder on shroud:** rejected — adds active or passive magnetic components to
  the shroud, increasing mechanical complexity and cost.
- **Optical encoder:** rejected — requires more complex shroud features (apertures or
  reflective strips) and additional LED/photodiode components on the PCB inner face.

### Impact

- `design/Electronics/Rotor/Design_Spec.md`: §1 (two-board architecture, Ø92mm PCBs, shroud
  description), §2.1 (rewritten for capacitive encoder with milled shroud flanges), §3.4
  (J_INT internal headers H_SW3/H_PWR/H_JTAG/H_SENS added), BOM split into Board A / Board B, FR/DR updated.
- `design/Electronics/Rotor/Board_Layout.md`: rewritten for Board A and Board B with
  stacking cross-section; all Ø100mm references updated to Ø92mm.
- `design/Electronics/Rotor/Rotor_64_Char_Design.md`: de Bruijn track replaced by 3+3
  dual-track reflected Gray code; XOR-chain decode; geometry updated to r=44mm / Ø92mm.
- `design/Electronics/Rotor/Rotor_26_Char_Design.md`: single-track all-on-Board-A confirmed;
  geometry updated to r=44mm / Ø92mm; U3 not-populated note added.
- `design/Electronics/Consolidated_BOM.md`: J_INT internal headers (H_SW3 PH1-07-UA/RS1-07-G, H_PWR PH1-05-UA/RS1-05-G, H_JTAG PH1-05-UA/RS1-05-G, H_SENS PH1-05-UA/RS1-05-G) added,
  4 headers per rotor assembly (120 total for 30 rotors).

---

## DEC-029 — Supercapacitor Hold-Up Specification: 25F Abracon Cells, 2S4P, ≥20 s at 15W

- **Status:** Accepted — 2026-04-14
- **Date:** 2026-04-14
- **Category:** Electrical
- **Area:** Power Module — Supercap Bank, Hold-up Specification
- **Supersedes:** DEC-004 (cell reference), DEC-021 (cell capacitance and count)
- **References:** DR-PM-07, DR-PM-09, BOM C_SC1–8

### Decision

The supercapacitor hold-up **minimum requirement is ≥20 seconds** at a **15W shutdown load**
(CM5 typical operating current: 5V × 3A = 15W). The confirmed cell selection (Abracon
ADCR-T02R7SA256MB, 25F/2.7V) in a **2S4P (8-cell)** arrangement provides ≥33.5 seconds.

> ⚠️ **Cell lock:** Cells are **Abracon ADCR-T02R7SA256MB, 25F/2.7V** in **2S4P (8 cells)**.
> Stale values **22F**, **33F**, **37.5F**, **21.7 s**, and **24.8 s** must never reappear.
> Any proposed cell or configuration change requires recalculating hold-up against the ≥20 s
> rule below using the **15W** load figure.

### Correct Load Figure

> ⚠️ The CM5 draws **5V × 3A = 15W** during typical operation. When a power-loss event
> occurs, the CM5 is running at this load and continues to draw it throughout the OS shutdown
> sequence (~10–15 s). Earlier documents used 5W (1A) which significantly overstated margin.
> **All hold-up calculations must use 15W** as the minimum design load.

### Configuration

| Parameter | Value |
| :--- | :--- |
| Cell part number | Abracon ADCR-T02R7SA256MB |
| Cell capacitance | 25F / 2.7V each |
| Configuration | 2S4P — 8 cells total (C_SC1–C_SC8) |
| Effective capacitance | 50F at 5.4V |
| Charge voltage (2S) | 5.4V |
| Block footprint | 37mm × 77mm (2 columns × 4 rows, 20mm pitch) |
| Shadow zone | 41mm × 81mm |

### Hold-Up Calculation

Usable energy from a capacitor bank discharged from V\_hi to V\_lo:

> **E = ½ × C × (V\_hi² − V\_lo²)**

Load power during shutdown: **P = 15W** (CM5 at 5V × 3A typical).

Hold-up duration: **t = E × η / P**

#### Conservative model (pure-buck — LTC3350 loses regulation at V\_lo ≈ 4.75V)

| Step | Calculation | Result |
| :--- | :--- | :--- |
| Usable energy | ½ × 50 × (5.4² − 4.75²) | 164.9J |
| Hold-up @ 15W | 164.9J / 15W | **11.0 s ❌** |

This model is unrealistic — the LTC3350 is a 4-switch synchronous buck-boost, not a simple
buck. It is shown here only to illustrate that relying on the cap voltage staying above the
output voltage is not sufficient at this load.

#### Realistic model (LTC3350 boost mode, V\_lo = 2.0V, η = 80%)

The LTC3350 actively boosts the supercap voltage to maintain 5V output in backup mode.
Minimum practical V\_CAP of ~2.0V protects cells from over-discharge (1.0V/cell for 2S).

| Step | Calculation | Result |
| :--- | :--- | :--- |
| Stored energy (V\_lo = 2.0V) | ½ × 50 × (5.4² − 2.0²) | 629J |
| Delivered (η = 80%) | 629J × 0.80 | **503J** |
| Hold-up @ 15W | 503J / 15W | **≥33.5 s ✅** |

#### Sensitivity to LTC3350 efficiency at 15W load

| Efficiency | Delivered energy | Hold-up | Pass ≥20 s? |
| :--- | :--- | :--- | :--- |
| 85% | 535J | 35.6 s | ✅ |
| 80% | 503J | 33.5 s | ✅ |
| 75% | 472J | 31.5 s | ✅ |
| 67% | 421J | 28.1 s | ✅ |
| 48% (minimum) | 302J | 20.1 s | ✅ (edge) |

The ≥20 s rule is satisfied even if converter efficiency degrades to ~48%, which is far below
any credible operating point for a synchronous buck-boost at these voltages and currents.

### Rationale

- **Why 2S4P (8 cells) and not 2S3P (6 cells)?** At 15W, 2S3P (37.5F) delivers 377J at 80%
  efficiency → 25.2 s. This passes the 20 s rule but leaves only 26% margin. 2S4P (50F)
  delivers 503J → 33.5 s, a 68% margin, providing meaningful headroom against LTC3350
  efficiency variation, higher CM5 loads during bring-up, and supercap aging.
- **Why 15W?** The CM5 module draws 5V × 3A under typical operating load. When power is lost,
  the OS shutdown sequence takes ~10–15 s during which the CM5 continues at near-full load.
  Using 5W (1A) as the design load significantly understates the required hold-up margin and
  was an error in DEC-004 and DEC-021.
- **0.5A PoE charge current (from DEC-004) retained:** charge power = 5.4V × 0.5A = 2.7W,
  unaffected by the cell count increase. Charge time from fully depleted ≈ **9 minutes**
  (100F per series position × 2.7V / 0.5A = 540 s). PoE utilisation calculations in
  Certification\_Evidence are unaffected.

### Constraints

- Do not change the cell MPN, cell count, or configuration without re-running the hold-up
  calculation at **15W** against the ≥20 s rule and updating DR-PM-07, DR-PM-09, and this DEC.
- LTC3350 CELLS register must remain configured for 2 series cells (CELLS = 0x01).
- PCB shadow zone: 41mm × 81mm. No traces on L1–L6 within this zone (enclosure rib clearway).

---

## DEC-030 — 5V_MAIN Backup Switchover Transient Fix (R14, R30, C35)

- **Status:** Accepted
- **Date:** 2026-04-14
- **Category:** Electrical
- **Area:** Power Module — LTC3350 Backup Switchover, 5V_MAIN Bulk Capacitance

### Issue

At 3A load (CM5 typical draw), the existing 5V_MAIN bulk capacitance (C9=22µF + C10=22µF +
C13=10µF = 54µF total) provides only 2.59µs before PWR_GD deasserts
(54µF × 144mV / 3A). The LTC3350 at default 200kHz (5µs/cycle) gets only 0.52 cycles
to complete backup switchover — INSUFFICIENT.

### Root Cause Analysis

- Old R14 = 28.7kΩ → backup threshold = 4.644V; PWR_GD deassert = 4.50V; gap = 144mV
- LTC3350 RT=INTVCC (no resistor) = 200kHz → 5µs/cycle
- 54µF × 144mV / 3A = 2.59µs = 0.52 cycles → FAILS

### Fix (three combined changes)

1. **R14: 28.7kΩ → 30.1kΩ** — raises backup threshold to 4.812V; new gap = 312mV
2. **R30: new 33.2kΩ resistor** (LTC3350 RT pin to GND) — sets switching frequency to 400kHz (2.5µs/cycle)
3. **C35: 2× Samsung CL32B226KAJNNNE** (22µF 25V X7R 1210) in parallel = 44µF additional bulk on 5V_MAIN

### Result with Fix

- Total bulk = 54µF + 44µF = 98µF
- Time window = 98µF × 312mV / 3A = **10.2µs**
- Cycles at 400kHz = 10.2µs / 2.5µs = **4.1 cycles ✓**
- False-trigger headroom: 5V×0.98 − 4.812V = 88mV (LTC3350 ~12µs deglitch filters brief dips)

### Component Selection Rationale for C35

- **Selected: 2× Samsung CL32B226KAJNNNE** (22µF 25V X7R 1210, existing BOM part)
  - ESR ≈ 10mΩ (negligible, stable −55°C to +125°C)
  - Uses existing qualified BOM part — no new component qualification needed
  - 4.1 cycles margin at all operating temperatures
- Evaluated and rejected: HZA107M025X16T-F (CDE hybrid polymer-Al, 30mΩ ESR, 4.56 cycles at
  +20°C but marginal 2.1 cycles at −40°C — not selected as existing BOM part is sufficient)
- Evaluated and rejected: KEMET T495X107K025ATA150 (MnO₂ tantalum, 150mΩ ESR — V_ESR = 450mV
  at 3A, EXCEEDS entire 312mV budget; also MnO₂ tantalum short-circuit failure mode is unsafe
  in low-impedance power supply)

### No Change Required To

- eFuse (HV input side)
- LDO TPS75733 (stays in regulation)
- MIC1555/R28/C32 (3.01s timing unchanged)

---

## DEC-031 — CM5 Virtual Keyboard (Key Injection) Feature Architecture

- **Status:** Decided
- **Date:** 2026-04-14
- **Category:** Electrical / Firmware
- **Area:** Stator Board — I²C Expanders, Servo, External Keyboard Source Mux
- **Author:** Izzyonstage & GitHub Copilot

### Summary

Design decision for enabling the CM5 to autonomously inject virtual keypresses into the Enigma
cipher pipeline, enabling automated rotor configuration testing and fully autonomous cipher operation.

### Problem

The Enigma machine requires a physical keypress to advance rotors and inject input into the cipher
pipeline. For autonomous CM5 operation (testing, remote cipher operation), a mechanism is needed to
inject keypresses without human intervention.

### Decision

Add three I²C expanders to the Stator board on the shared I²C-1 bus:

1. **MCP23017 @ 0x20 (U6):** 16-bit GPIO expander for ENC_IN/ENC_OUT monitoring. Replaces
   CM5 GPIO 4–15 (12 pins freed).
   - GPA[5:0] = ENC_IN[5:0] monitor (inputs)
   - GPB[5:0] = ENC_OUT[5:0] monitor (inputs)
   - GPA[6:7], GPB[6:7] = spare

2. **MCP23017 @ 0x21 (U7):** 16-bit GPIO expander for virtual key data injection, external
    keyboard-source mux control, and SYS_RESET_N (replaces CM5 GPIO 26 — 1 pin freed).
    - GPA[5:0] = CM5_KEY_DATA[5:0] (outputs — 6-bit virtual key data bus)
    - GPA[6] = KEY_CM5_ACTIVE (output — mux select: 0=physical keyboard, 1=CM5 virtual)
    - GPA[7] = SYS_RESET_N (output — system-wide CPLD reset)
    - GPB[7:0] = spare / reserved

### Rationale for MCP23017 (×2)

- 32 GPIO total provides headroom for future I/O expansion.
- SYS_RESET_N migration to expander reduces LINK-BETA pin count and frees CM5 GPIO 26.
- All keyboard-source mux and reset control signals remain co-located with the Stator CPLD.
- Only 2 wires (I²C SDA/SCL) needed on LINK-BETA instead of 13 discrete signal pins.

### External Keyboard Source Mux

- GPA[6] on U7 drives `KEY_CM5_ACTIVE` for the external keyboard-source mux at the Stator
  keyboard-source entry point.
- `KEY_CM5_ACTIVE=0`: the physical keyboard 6-bit source bus is forwarded to the encryption pipeline.
- `KEY_CM5_ACTIVE=1`: `CM5_KEY_DATA[5:0]` is forwarded instead.
- The selected implementation uses `U4` and `U5`, both `74HC157PW-Q100,118` quad 2:1 mux devices,
  to cover the 6-bit path, with both `E` pins tied to GND so the mux is always enabled while the
  board is powered.
- GPA[7] now carries `SYS_RESET_N`, fully populating the U7 GPA port and leaving U7 GPB
  completely spare / reserved for future use.

### Net Effect on LINK-BETA

- **Freed (13 pins):** ENC_IN[5:0] (×6), ENC_OUT[5:0] (×6), SYS_RESET_N (×1).
- **Freed:** pins 8 (SYS_RESET_N), 12–17 (ENC_IN[5:0]), and 19–24 (ENC_OUT[5:0]) were freed by this decision.
- **Later reuse:** DEC-036 reallocated the former monitor block into grouped LINK-BETA power rails
  (5V_MAIN, 3V3_ENIG, and GND) once the Stator-side 5V needs were formalised.
- R6 pull-up (10kΩ to 3V3_ENIG) on Stator keeps SYS_RESET_N HIGH at power-up (CPLDs out of reset).

### Net Effect on CM5 GPIO

- **Freed (13 pins):** GPIO 4–15 (ENC monitoring), GPIO 26 (SYS_RESET_N).
- No new CM5 GPIO assignments required.

### I²C Bus Address Map (no conflicts)

| Address | Device | Location |
| :--- | :--- | :--- |
| 0x09 | LTC3350 | Power Module |
| 0x0B | Smart Battery | Power Module |
| 0x20 | MCP23017 (U6) | Stator |
| 0x21 | MCP23017 (U7) | Stator |
| 0x22 | MCP23017 (U8) | Stator |
| 0x23 | MCP23017 (U1) | Settings Board |
| 0x24 | MCP23017 (U2) | Settings Board |
| 0x25 | MCP23017 (U3) | Settings Board |
| 0x28 | STUSB4500 | Power Module |
| 0x40 | INA219 (U12) | Power Module |
| 0x45 | INA219 (U2) | Stator |

---

## DEC-032 — Settings Board: Panel-Mount Configuration Controls with CM5 Override

- **Status:** Decided
- **Date:** 2026-04-14
- **Category:** Electrical / HMI
- **Area:** Stator Board — Configuration Interface; new Settings Board PCB
- **Author:** Izzyonstage & GitHub Copilot

### Summary

Replace the Stator Board's DIP switches (routing + reflector map) with panel-mount toggle switches
plus discrete RGB indicators on a dedicated Settings Board PCB. The Settings Board connects to the
Stator via I²C only (no parallel signal wiring). A new MCP23017 expander (U8 @ 0x22) on the
Stator Board bridges the I²C configuration data to the CPLD config input pins and issues the
Stator-only `CFG_APPLY_N` reload pulse.

### Problem

The Stator's DIP switches (SW1, SW2) are internal PCB components, requiring the enclosure to be
opened to change the routing or reflector map configuration. This is inconvenient for regular use.
Additionally, the CM5 has no way to programmatically override the configuration.

### Decision

1. Remove SW1 and SW2 from the Stator Board.
2. Add a new Settings Board PCB (panel-mount, right side of enclosure top face near rotors) with:
   - 10 panel toggle switches plus 12 discrete RGB indicators (Bank 1 = 4 config toggles + 1 source-status LED, Bank 2 = 6 config toggles + 1 source-status LED)
   - 1 momentary active-low `CFG_APPLY_N` input; a board-mounted tactile switch actuated through the enclosure is acceptable
   - U1 (MCP23017 @ 0x23): reads the Settings Board user-intent config plus `CFG_APPLY_N`
   - U2 (MCP23017 @ 0x24): drives Bank 1 LED anodes + Bank 1 colour rails
   - U3 (MCP23017 @ 0x25): drives Bank 2 LED anodes + Bank 2 colour rails
3. Add U8 (MCP23017 @ 0x22) to the Stator Board. Its outputs drive the CPLD configuration
   input pins directly (`CFG_ROUTE[3:0]` and `CFG_REFMAP[5:0]`). Pull-downs R16–R26 are retained on the CPLD
   input pins to hold safe defaults (all-zero) at power-up before CM5 initialises U8.
4. CM5 firmware (enigma daemon):
   - Reads U1 to get user-intent config state
   - Decides in software whether each bank forwards user intent or uses a CM5-defined preset
   - Drives the bank source indicators via `CFG_ROUTE_CM5_ACTIVE` / `CFG_REFMAP_CM5_ACTIVE`
     (green = user intent forwarded, red = CM5-defined)
   - After writing final config to U8, pulses `CFG_APPLY_N` (U8 GPA[4]) LOW→HIGH to
     trigger a Stator-only configuration reload
5. Physical `CFG_APPLY_N` button on Settings Board: reads via U1 GPB[7]; CM5 daemon polls
   this and triggers the same U8 write + `CFG_APPLY_N` pulse when pressed. The switch may be
   a board-mounted tactile part with a simple actuator/plunger through the enclosure rather than a
   true panel-mount pushbutton.

### LED Colour Scheme

- **Green illumination:** Bank is forwarding Settings Board user intent; illuminated bits show the active forwarded configuration.
- **Red illumination:** Bank is in CM5-defined mode; illuminated bits show the CM5-programmed configuration.
- Per-bank shared colour rail: all switches in a bank share the same colour (green or red) while individual anode control shows which bits are set.

### I²C Address Assignments (new)

| Address | Device | Location |
| :--- | :--- | :--- |
| 0x22 | MCP23017 (U8) | Stator — CPLD config output driver |
| 0x23 | MCP23017 (U1) | Settings Board — switch input reader |
| 0x24 | MCP23017 (U2) | Settings Board — Bank 1 LED anode + colour rail driver |
| 0x25 | MCP23017 (U3) | Settings Board — Bank 2 LED anode + colour rail driver |

### Rationale

- Replacing DIP switches with panel toggles makes configuration user-accessible without opening the enclosure.
- I²C-centric wiring between Settings Board and Stator keeps the cable harness minimal vs 10+
  parallel signal wires; the active harness is now a 6-wire JST PH link carrying `3V3_ENIG`,
  `5V_MAIN`, `GND`, `SDA`, `SCL`, and a dedicated LED return GND.
- Retaining R16–R26 pull-downs ensures the CPLD receives a safe all-zero default at power-up
  (no plugboard insertion, physical reflector pass-through) before the CM5 writes the desired config.
- CM5 remains the single authority arbiter, allowing GUI presets to forward or override the Settings
  Board user-intent image while still exposing that authority state through the indicators.
- RGB illumination (green/red) provides immediate visual feedback on configuration source with no
  additional UI required.

> **Supersession note:** This decision records the original Settings Board migration intent. The
> active address map and harness definition were later refined by the post-audit cleanup:
> `U1 @ 0x23`, `U2 @ 0x24`, `U3 @ 0x25`, and a 6-wire JST PH harness carrying
> `3V3_ENIG`, `5V_MAIN`, `GND`, `SDA`, `SCL`, `GND`.

### Impact

- **Stator Board:** SW1 and SW2 removed; U8 and J13 added; `CFG_APPLY_N` added to the Stator-only reset/apply path
- **New Board:** Settings Board added to system BOM
- **Firmware:** enigma daemon startup sequence must: read U1, determine final applied config,
  write U8, pulse `CFG_APPLY_N`, update U2 / U3
- **CPLD / reset path:** the Stator-only `CFG_APPLY_N` pulse is combined with `SYS_RESET_N` so the
  Stator CPLD can be reloaded without forcing a global system reset; implemented with
  `SN74LVC1G08DBVR` on the Stator

---

## DEC-033 — DSI1 Display Connector Provision for Optional Lid Touchscreen

- **Status:** Decided
- **Date:** 2026-04-14
- **Category:** Electrical / HMI
- **Area:** Controller Board — CM5 display interface; Main Enclosure lid
- **Author:** Izzyonstage & GitHub Copilot

### Summary

Add a DSI1 4-lane FPC connector (J9) to the Controller Board to provision for an optional
lid-mounted touchscreen display, enabling the Enigma-NG to operate as a self-contained machine
without an external monitor. The Display Add-on Board design is deferred.

### Problem

The Enigma-NG currently relies on an external HDMI monitor and USB HID devices for system
management and GUI display. With the CM5 virtual keyboard injection (DEC-031) and Settings Board
(DEC-032) features, the machine is capable of autonomous operation. Adding a lid-mounted touchscreen
completes the self-contained package — the only remaining external peripheral would be a keyboard
and mouse for system administration tasks.

### Decision

1. Add J9 (Amphenol F52Q-1A7H1-11015, 15-pin 1.0mm pitch ZIF/FPC connector) to the Controller Board to expose
   the CM5 DSI1 4-lane interface (CLK +/−, D0–D3 +/−).
2. Route DSI1 differential pairs on L3 (100 Ω differential stripline — same rule as HDMI/USB).
   Traces run from CM5 mezzanine connector pins to J9 near the CM5 socket.
3. Touch I²C (capacitive touch controller SDA/SCL) is routed via the I²C-1 bus already present
   on the Controller Board.
4. `J9` is the only Controller-side display connector fixed in the current scope. Any future
   display power or auxiliary touch wiring remains deferred with the display add-on board definition.
5. The HDMI port (J4) is retained and unaffected — J9 is additive.
6. Display Add-on Board design (lid mounting frame, FPC cable assembly, backlight driver if
   required, touch controller interface) is **deferred** to a future design phase.

### Display Interface

- **Interface:** MIPI DSI1 (4-lane)
- **Differential impedance:** 100 Ω (same as HDMI — no new routing rules)
- **Connector:** Amphenol F52Q-1A7H1-11015 — 15-pin 1.0mm pitch right-angle ZIF/FPC
- **Cable:** Thin FPC routed through lid hinge area (far superior to HDMI cable for hinge flexing)
- **Touch input:** Capacitive touch controller I²C on I²C-1 bus (existing bus, no new wires required)
- **Supported sizes:** DSI1 4-lane supports displays up to 10" at full resolution (e.g., RPi official 10" touchscreen)

### Rationale

- DSI1 FPC cable is thin and flexible — ideal for routing through a lid hinge without fatigue.
- Retaining HDMI preserves external monitor compatibility for development and maintenance.
- The 100 Ω differential rule is already established on L3 for HDMI — no new stackup or impedance work needed.
- Provisioning the connector now (no extra cost, trivial PCB area) avoids a board revision later if the display add-on is adopted.
- I²C-1 bus already has spare address space for a touch controller (e.g., FT5426 at 0x38 or similar).

### Impact

- **Controller Board:** J9 added; ~10 new 100 Ω diff traces on L3; small ZIF footprint on L1 near CM5
- **Main Enclosure:** Lid requires provision for display mounting and FPC hinge routing (see `Main_Enclosure/Design_Spec.md`)
- **Display Add-on Board:** Deferred — to be designed as a separate optional add-on
- **Firmware / OS:** Standard RPi DSI1 display driver; no custom firmware changes needed for basic display output

---

## DEC-034 — Switch Hardware Refresh: Settings Board Toggle + Discrete RGB LED, Ruggedized PM SW1

- **Status:** Decided
- **Date:** 2026-04-16
- **Category:** Electrical / HMI / Mechanical interface
- **Area:** Settings Board; Power Module front-panel switchgear
- **Author:** Izzyonstage & GitHub Copilot

### Summary

Replace the old unified Marquardt rocker-switch assumption with two purpose-specific solutions:
E-Switch 200-series toggle switches plus discrete RGB LEDs on the Settings Board, and the Adafruit
4660 rugged metal RGB latching switch for Power Module SW1.

### Problem

The previous design direction forced the Settings Board and Power Module onto one shared switch
family even though the two locations serve different aesthetic, mechanical, and service roles. The
Settings Board benefits from classic toggle controls with separate indicators, while the Power Module
benefits from a sealed, rugged metal power switch with a more robust panel interface and
spade-terminal wiring.

### Decision

1. **Settings Board switch selection:** Use `200MSP1T2B4M2QE` for the 10 configuration toggles
   (`SW_B1[3:0]`, `SW_B2[5:0]`).
2. **Settings Board LED selection:** Use `WP154A4SEJ3VBDZGW/CA` for all 12 Settings Board indicators
   (10 config-bit indicators + 2 source-status indicators).
   - Kingbright 5mm common-anode RGB through-hole LED
   - Full RGB operation is available under CM5 control
   - Separate red, green, and blue series resistors per switch allow colour balancing under nominal 5V operation
3. **Settings Board LED topology update:** Change the indicator drive from the previous
   common-cathode / PNP sourcing concept to:
   - individual LED anode drive from `U2` / `U3`
   - per-bank red / green / blue shared cathode rails
   - low-side BSS138 sink devices on each bank colour rail
4. **Power Module switch selection:** Use Adafruit `4660` for `SW1`.
   - Latching rugged metal power switch
   - RGB ring illumination
   - 16mm panel cutout
   - 2.8mm pin terminals routed to PCB-mounted 2.8mm male spade tabs for serviceable harnessing

### Rationale

- The Settings Board now matches the machine's more period-correct control aesthetic better than a
  rocker-based panel.
- Separate LEDs give more freedom over indicator placement and future panel detailing than
  integrated illuminated switches.
- The Power Module switch benefits from a tougher sealed metal body and clearer power-switch
  identity than the previous shared-family concept.
- Breaking the false BOM unification removes a mechanical compromise that was not buying any real
  electrical simplification.

### Impact

- **Settings Board Design_Spec / Board_Layout:** switch type, LED type, and LED driver polarity all
  change
- **Consolidated BOM:** split the old shared rocker line into distinct Settings Board and Power
  Module entries
- **Power Module Design_Spec:** SW1 selection and harnessing updated to the rugged metal switch
- **Copilot handoff / component tracking:** the old Marquardt-all-13-switches assumption is retired

---

## DEC-035 — HID Keyboard and Lightboard Use a 40-Position QWERTY-Derived Layout for the 64-Character Code Space

- **Status:** Decided
- **Date:** 2026-04-17
- **Category:** HMI / Mechanical interface / HID logic
- **Area:** HID Assembly; Encoder Board; Rotor actuation interface
- **Author:** Izzyonstage & GitHub Copilot

### Summary

Freeze the HID operator interface as a **40-position physical layout** rather than a 64-key physical
array. The printable positions are `[a-z0-9+=]`, with **Left Shift** and **Right Shift** on the
bottom row to access uppercase alphabetic codes. The machine still retains its full 64-character
logical alphabet.

### Problem

Older docs had drifted toward describing the HID assembly as a literal 64-key keyboard, which no
longer matched the intended operator experience. That made the purchased keyboard-switch quantity,
mechanical lever count, and Encoder input mapping ambiguous, and risked re-introducing separate
uppercase-only key positions that were never part of the intended user-facing layout.

### Decision

1. **Physical keyboard layout:** Use **40 total switch positions** in the HID keyboard.
   - 26 lowercase alphabetic keycaps: `a-z`
   - 10 numeric keycaps: `0-9`
   - 2 symbol keycaps: `+` and `=`
   - 2 modifier keycaps: **Left Shift** and **Right Shift**
2. **Logical 64-character repertoire:** Preserve the full 64-character code space in Encoder logic.
   - Unshifted alphabetic keys emit `a-z`
   - Shifted alphabetic keys emit `A-Z`
   - Digits and `+` / `=` are unchanged by Shift
   - Therefore the HID path still covers 26 lowercase + 26 uppercase + 10 digits + 2 symbols = 64
     unique character codes
3. **Physical lightboard layout:** Mirror the same QWERTY-derived printable positions on the
   lightboard instead of introducing dedicated uppercase-only legends or lamp locations.
4. **Mechanical interface:** The rotor actuation mechanism shall therefore be designed around
   **40 physical key levers**, not 64.

### Rationale

- This matches the intended operator experience of a keyboard-like panel instead of an abstract
  64-button matrix.
- It preserves the full 64-character cipher alphabet without wasting front-panel area on
  duplicated uppercase-only key positions.
- It aligns the purchased custom keyboard switch count and the HID mechanical packaging with a more
  realistic enclosure layout.

### Impact

- **HID Assembly Design_Spec:** layout, key count, and purchased switch definition fixed at 40
  positions
- **Encoder Design_Spec:** HID mapping clarified as 40 physical inputs projected into a 64-code
  logical space
- **Rotor Actuation Assembly:** lever count reduced from 64 to 40
- **Consolidated BOM / component tracking:** keyboard switch quantity updated to 40 and tied to the
  pseudo datasheet for the purchased marketplace part

---

## DEC-036 — LINK-BETA Former Monitor Pins Reallocated as Grouped Power Rails

- **Status:** Decided
- **Date:** 2026-04-18
- **Category:** Electrical / Power distribution
- **Area:** Controller Board J2 (LINK-BETA), Stator Board J8, Settings/Servo 5V branch
- **Author:** Izzyonstage & GitHub Copilot

### Summary

Keep LINK-BETA as the 40-pin Samtec ERF8/ERM8 pair from DEC-015, but stop carrying a large legacy
spare block. Reallocate the former ENC monitor positions into grouped power rails: **4 contiguous
5V_MAIN pins**, **3 additional 3V3_ENIG pins**, and **3 additional GND return pins**.

### Problem

After DEC-031 migrated ENC_IN/ENC_OUT monitoring and SYS_RESET_N to Stator-side I²C expanders, a
large section of LINK-BETA remained unused. That left the connector under-utilised while the
Stator-side 5V branch had only 2 pins (1.0A connector capacity) available for the servo and the
Settings Board indicator rail.

### Decision

Retain the 40-pin LINK-BETA connector and apply this active allocation:

| Pin | Signal | Direction | Notes |
| :--- | :--- | :--- | :--- |
| 1 | GND | — | JTAG leading shield |
| 2 | TCK | CTRL→Stator | JTAG clock |
| 3 | GND | — | TCK/TMS inter-pin shield |
| 4 | TMS | CTRL→Stator | JTAG mode select |
| 5 | GND | — | TMS/TDI inter-pin shield |
| 6 | TDI | CTRL→Stator | JTAG data in |
| 7 | GND | — | TDI/GND inter-pin shield |
| 8 | GND | — | Extra JTAG trailing/guard ground |
| 9 | GND | — | JTAG trailing shield |
| 10 | GND | — | Isolation moat pin 1 |
| 11 | GND | — | Isolation moat pin 2 |
| 12 | I2C1_SDA | Bidir | Shared Stator/Settings I²C-1 data extension |
| 13 | I2C1_SCL | Bidir | Shared Stator/Settings I²C-1 clock extension |
| 14 | 5V_MAIN | PM→Stator | Grouped 5V_MAIN feed |
| 15 | 5V_MAIN | PM→Stator | Grouped 5V_MAIN feed |
| 16 | 5V_MAIN | PM→Stator | Grouped 5V_MAIN feed |
| 17 | 5V_MAIN | PM→Stator | Grouped 5V_MAIN feed |
| 18 | GND | — | 5V_MAIN return moat |
| 19 | 3V3_ENIG | PM→Stator | Additional 3V3_ENIG feed |
| 20 | 3V3_ENIG | PM→Stator | Additional 3V3_ENIG feed |
| 21 | 3V3_ENIG | PM→Stator | Additional 3V3_ENIG feed |
| 22 | GND | — | Grouped return for the mixed-power block |
| 23 | GND | — | Grouped return for the mixed-power block |
| 24 | GND | — | Grouped return for the mixed-power block |
| 25 | GND | — | TTD_RETURN leading shield |
| 26 | TTD_RETURN | Stator→CTRL | JTAG TDO short-path return |
| 27 | GND | — | TTD_RETURN trailing shield |
| 28–35 | 3V3_ENIG | PM→Stator | Existing 3V3_ENIG pass-through block |
| 36–40 | GND | — | Main power return block |

### Rationale

- The connector footprint, mating safety, and stack geometry from DEC-015 stay unchanged.
- Grouping all four 5V_MAIN pins together simplifies routing and clearly separates the 5V branch
  from the I²C and JTAG regions.
- 4 × 5V_MAIN pins provide **2.0A connector capacity**, giving ample headroom above the current
  0.74A downstream budget (Settings Board indicators + servo).
- The extra 3V3_ENIG pins make LINK-BETA electrically overprovisioned, so the upstream 3.0A LDO
  remains the only practical 3V3 limit.

### Impact

- Controller / Stator LINK-BETA tables updated to grouped 5V_MAIN, 3V3_ENIG, and GND allocations
- Settings Board and Stator docs updated to source `5V_MAIN` from LINK-BETA pins **14–17**
- Historical Controller probe-access concept repurposed from unused spare pads to power/I²C
  bring-up probes

### Cross-ref

DEC-015 (40-pin connector retained). DEC-031 (freed the former monitor pins). DEC-034
(Settings Board full-RGB 5V indicator branch creates a standing Stator-side 5V load). DEC-040
(all Diagnostics Banks removed from active specs; revisit only during coupon review).

---

## DEC-037 — LINK-BETA Pin Map Regrouped Around Dedicated JTAG and I2C Guard Bands

- **Status:** Decided
- **Date:** 2026-04-18
- **Category:** Electrical / Interconnect definition
- **Area:** Controller Board J2 (LINK-BETA), Stator Board J8, historical Controller bring-up probe concept
- **Author:** Izzyonstage & GitHub Copilot

### Summary

Retain the 40-pin LINK-BETA connector from DEC-015, but replace the DEC-036 allocation with a cleaner
rail-and-guard arrangement: front power cluster, front 3V3 cluster, dedicated guarded JTAG block,
guarded I2C pair, then a rear power cluster. This becomes the only active LINK-BETA pin-definition
table.

### Problem

DEC-036 solved the spare-pin problem, but the resulting active map split `3V3_ENIG` into a small
middle block plus a rear block and left the overall pin order harder to reason about in board docs
and bring-up references. The design intent now is to preserve a dedicated guarded JTAG region, keep
`TTD_RETURN` near that JTAG region, keep I2C shielded, and make the remaining rails cleaner to read
without relying on historical "additional" or "pass-through" distinctions.
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

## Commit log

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2026-03-27 Add detailed design document for Power Module
    Document the detailed design specifications for the Shielded Power Module, including hardware specs, EMI filtering, safety features, and manufacturing details.
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2026-04-01 Pin checks and logic component consistency.
    Removed references to iCE40, replaced with EPM240T100C5N.
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2026-04-03 docs: comprehensive design documentation consistency pass
    Apply finalized component selections across all design documents:
    Power Module (PoE):
    - Replace Silvertel Ag5300/Ag53000 with discrete TPS2372-4 + TPS23730 + T2 ACF design
    - T2: custom EF20 transformer, Np:Ns 2.8:1, Lm 150-200uH, >=1500Vrms, 51W/250kHz
    - System capacity: 72W; steady-state utilisation: 70.8%
    - OA-03 closed; OA-08 opened for Wurth Elektronik transformer engagement
    Supercapacitors:
    - Replace Eaton HV1030-3R0156-R (6x 15F/3.0V, 2x3 block) with Tecate TPLH-2R7/22WR12X31 (4x 22F/2.7V, 2S2P)
    - Relocate bank to 5V_MAIN bus (was 15V input side)
    - Add LTC3350 (QFN-28) supercap manager
    - 11F at 5.4V; 72.4J hold-up energy; ~14.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
2026-04-03 Power Module: reduce LTC3350 charge current to 0.5A, fix hold-up vs charge time, close OA-02
    - LTC3350 RICHARGE: programmed for 0.5A charge current (halved from 1A)
    - Charge time from cold: ~2 minutes (was incorrectly stated as '14 seconds' — that is hold-up time)
    - Hold-up time once charged: 14.5s (unchanged)
    - PoE utilisation during charge: 71.8% (was 75.8% at 1A — now within 75% rule)
    - PoE steady-state utilisation: 67.9% (unchanged)
    - OA-02: closed — 75% rule now met at all times on all sources
    - User Manual: intro DefStan reference removed; 2-min charge warm-up noted
    - Cert Evidence: table, footnote and OA-02 updated accordingly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
2026-04-03 Remove all DefStan references across project
    DefStan 59-411 and 00-35 compliance is deferred pending access to an
    accredited MOD review environment. All references replaced with:
    - CE/UKCA applicable standards (EN 55032, EN 55035, IEC 60068-2)
    - Forward-looking notes about future military certification assessment
    - Temperature derating basis changed from 70°C (DefStan Land Class C)
    to 55°C (IEC 60068-2 industrial maximum ambient)
    Files updated:
    - design/Standards/Certification_Evidence.md (11 edits)
    - design/Guides/User_Manual.md (1 edit)
    - design/Electronics/Boards_Overview.md (1 edit)
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2026-04-03 Resolve all open INC items and create Design_Log
    Tier 1 + Tier 2 consistency fixes:
    - INC-04: TPS25750 5V/6A -> 5V/5A (Design_Spec x2)
    - INC-05: Remove 3V3_SYSTEM from Link-Alpha pins 21-24; reallocate
    pins 21-22 -> 5V_MAIN, pins 23-24 -> GND (9A cluster total)
    ETH LED diagram: 3V3_SYSTEM -> 3V3_ENIG (local); PIN 27 -> PIN 26
    Diagnostic Bank-Alpha pin 14: 3V3_SYSTEM -> GND
    - INC-08: I2C pull-ups referenced rail 3V3_SYSTEM -> 3V3_ENIG
    - INC-10: R1-2/R3 -> R7-8/R9 in Design_Spec telemetry section;
    BOM designators R_UVLO_HI/LO/R_OVLO -> R1/R2/R3; add R7/R8/R9 rows
    - INC-11: BATT_PRES_N pull-up 3V3_SYSTEM -> 3V3_ENIG
    - INC-12: '6A Delivery Cluster' -> '9A Delivery Cluster' in Controller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
2026-04-03 Resolve DEC-011: All power rails generated on Power Module
    Architectural rule established: ALL power rails are generated on the
    Power Module. The Controller Board routes rails to downstream boards
    only. No power generation components belong on the Controller Board.
    Changes:
    - Power_Module/Design_Spec.md: Add 3V3_ROTOR (5A dedicated rotor
    stack rail, enabled by ROTOR_EN); update to 4-island L3 Power Plane
    (adds 3V3_ROTOR island); split 3V3_ENIG description to correctly
    scope it to CPLDs/JTAG/logic only
    - README.md: Remove Rotor Buck from Controller Board section;
    clarify as Power Module 3V3_ROTOR rail routed via Controller Board;
    update Power Module outputs to list 3V3_ROTOR
    - Cont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
2026-04-03 Consolidate 3V3_ROTOR into 3V3_ENIG; remove erroneous 5A rotor spec
    The separate 3V3_ROTOR (5A) rail introduced in the previous commit was
    a specification error — a confusion with the 5V/5A CM5 supply. The
    rotor stack is powered by the existing 3V3_ENIG rail (TPS7A8333P LDO,
    3A) along with all other 3.3V consumers.
    - Power_Module/Design_Spec.md: Remove 3V3_ROTOR; revert to 3-island
    L3 Power Plane; 3V3_ENIG scope expanded to include rotor stack
    - README.md: Remove 3V3_ROTOR from outputs; update rotor rail note to
    reference 3V3_ENIG correctly
    - Controller/Design_Spec.md: ROTOR_EN is LDO enable (not buck enable)
    - Rotor/Design_Spec.md: Source is 3V3_ENIG (not 3V3_ROTOR)
    - Design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
2026-04-03 Power Module gap closure: engineering calcs, shutdown sequence, full pin map
    - Design_Spec.md:
    - Fix 5V rail capacity: 5A -> 12A (dual-phase LMQ61460-Q1)
    - Add PoE subsystem detail: PSR mode confirmation, RMPS calc (121kOhm),
    Autoclass (no external RCLASS), TPS23730 VS-pin config
    - Add LDO enable circuit: ROTOR_EN (GPIO 16) -> TPS7A8333P EN pin,
    10kOhm pull-up to 5V_MAIN for default-on behaviour
    - Add RICHARGE calculation: 301 Ohm (E96) for 0.5A with 10mOhm RSENSE
    - Add LTC3350 backup trigger threshold and hold-up duration spec
    - Add new Sec 3 Shutdown Sequence (7-step graceful shutdown)
    - Add new Sec 4 eFuse Latch-Off Recovery procedure
    - Add new Sec 7 Thermal Budget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
2026-04-03 H2: Document complete EMI filter topology with values and calculations
    - Design_Spec.md §4 EMI & Filtering ('Iron Curtain'):
    - Replace bullet skeleton with full two-stage filter specification
    - ASCII topology diagram: L1 (WE-CMBNC CMC) -> L2 (Laird HF CMC) -> Pi (L3, C1-C6)
    - Stage 1 (L1): Würth WE-CMBNC nanocrystalline CMC, >=10A, >=1.5mH
    - Broadband CM: 1kHz-10MHz, mu_r > 50000, >60dB insertion loss at 150kHz
    - Stage 2 (L2): Laird CM5022 HF ferrite CMC, >=10A
    - Supplements nanocrystalline above 10MHz; ensures >40dB CM to 30MHz+
    - Stage 3 (L3 + C1-C6): Differential-mode Pi-filter
    - L3: Würth WE-PD 7447789100, 10uH, 14.5A Isat, 20mOhm DCR
    - C1/C4: 22uF 50V X7R 12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
2026-04-03 BOM: populate supplier part numbers, fix package errors and invalid PNs
    - D2 TPD2E2U06DRLR: fix package SON-6 -> SOT-563 (DRL); add Mouser 595-TPD2E2U06DRLR, DigiKey 296-38361-1-ND
    - U3 LTC3350EUHF#PBF: critical fix package QFN-28 -> QFN-38 (5x7mm); add Mouser 584-LTC3350EUHF#PBF, fix DigiKey (EUHE->EUHF T&R: LTC3350EUHF#TRPBFCT-ND)
    - U8 MCP121T-450E/LB: update package SOT-23-3 -> SC70-3 to match /LB orderable variant; add Mouser/DigiKey
    - U1 TPS259803ONRGER: replace invalid placeholder TPS25980RPWR with correct 16.9V OVLO VQFN-24 PN; add Mouser/DigiKey (flagged for verification)
    - U10 TPS23730RMCT: fix HTSSOP-20 (PWPR) -> WQFN-20 (RMCT) in Design_Spec and Consolidated_BOM
    - U4 TPS25750: add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
2026-04-03 fix(bom): critical PN corrections for R12, L1/L2/L3 and ERJ tolerance labels
    - R12: CSS2H-2512R-L100ELF -> CSS2H-2512R-R010ELF (L-prefix = uOhm range;
    R010 = 10mOhm as intended). Incorrect PN would have ordered 100uOhm shunt.
    - L1: confirmed as Würth WE-CMBNC 7448031002 (10A, 2mH, nanocrystalline).
    Add Mouser 710-7448031002 and Newark 75X1218 as primary stock source.
    - L2: Laird CM5022 DISCONTINUED (Laird absorbed by TE Connectivity 2019).
    Replace with second WE-CMBNC 7448031002; twin nanocrystalline CMC approach
    provides adequate broadband CM attenuation 1kHz-30MHz. Flag for review at
    EMC pre-compliance testing.
    - L3: Add verification warning - 7447789100 not confirmed in public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
2026-04-03 fix(bom): replace U4 TPS25750 (NRND) and L3 Würth non-catalog part
    U4 TPS25750 -> TPS25751DREFR:
    - TPS25750 was NRND; PD emulation is required so CM5 OS does not throttle.
    - TPS25751D is PD3.1 certified (TID#10306) with integrated 20V/5A bi-
    directional power path for DRP source operation at 5V/5A.
    - Package change: QFN-28 -> WQFN-38 6x4mm (REF). Schematic symbol and
    PCB footprint must be updated before layout.
    - Mouser: 595-TPS25751DREFR; DigiKey: TPS25751DREFR-ND.
    L3 7447789100 -> Bourns SRP1265A-100M:
    - Würth 7447789100 is not available in any public distributor catalog.
    - SRP1265A-100M: 10uH, 15.5A Isat (21% headroom over 12A rail),
    DCR=16.5mOhm max (better than 20mOhm spec), sh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
2026-04-03 fix(bom): correct J3 Molex battery connector MPN 43045-0512 -> 43650-0519
    43045-0512 does not exist at any distributor (Molex, Octopart, DigiKey all
    return zero results). The 43045 series is the SMT/right-angle Micro-Fit 3.0
    variant; the correct through-hole vertical PCB header family is 43650.
    Correct part: 43650-0519 (5-circuit, 1-row, vertical THT, gold contacts,
    board lock, 3mm pitch, Micro-Fit 3.0). Confirmed in stock:
    - Farnell ~1,143 pcs @ £1.18
    - Heilind 756 pcs
    Mouser: 538-43650-0519; DigiKey: WM7843-ND (infer - verify before order).
    Consolidated_BOM S10 Molex supplier note updated with corrected PN.
2026-04-03 Design_Log: add INC history, connector inventory; fix stale part refs
    - Design_Log.md: added full INC Review History (all 23 items with descriptions,
    original values, corrections and status) and Board Connector Inventory (all
    boards: Power Module, Controller, Stator, Rotor x30, Encoder, Reflector,
    Extension, JTAG Daughterboard)
    - Stale part reference cleanup across 7 files:
    * Power_Module/Design_Spec.md: J3 43045-0512 -> 43650-0519 in text; L2
    narrative updated to WE-CMBNC 7448031002 (Laird CM5022 removed); L3
    narrative updated to Bourns SRP1265A-100M; TPS25750 -> TPS25751DREFR in
    narrative sections
    * Power_Module/Board_Layout.md: TPS259474L -> TPS25980; TPS25750 -> TP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
2026-04-03 Fix spec errors from deep review: pins, packages, rail names; add datasheet links
    - Board_Layout.md: rewrite Power Handshake diagram with correct pin groups
    (5V_MAIN on PINS 21-22 + 49-80, 3V3_ENIG on PINS 39-44, ETH LEDs on PINS 25-26,
    PWR_GD on PIN 34, ROTOR_EN on PIN 46) and correct supervisor ref (U8 MCP121T)
    - Board_Layout.md: fix I2C BtB pin numbers (PIN 32/34 -> PIN 35/36 per
    authoritative Controller/Board_Layout.md)
    - Design_Spec.md: fix LTC3350 package references (QFN-28 -> QFN-38 5x7mm) in
    executive summary and component description sections
    - Design_Spec.md: fix rail name (+5V_SYSTEM -> 5V_MAIN) in Safe-Start Logic section
    - Design_Spec.md: fix U2A/U2B package (VQFN-15-HR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
2026-04-04 B1/B2/B3/Q1/Q3: Add missing Power Module components and fix spec gaps
    B1 - Re-add Q1-Q3 OR-ing MOSFETs (TI CSD17483F4T, 30V/10A N-ch SON-8):
    Three ideal-diode FETs for LM74700-Q1 triple-input OR-ing network.
    One per power input (PoE, USB-C, Battery). Note added to verify U6
    instance count at schematic capture.
    B2 - Add USB-C connector as J4 (GCT USB4135-GF-A):
    24-pin SMT USB-C receptacle, 5A rated, CC1/CC2 for STUSB4500 PD
    negotiation. Battery connector remains J3. Updated Board_Layout.md
    USB-C section label from J3 to J4.
    B3 - Add LTC3350 BACKUP pin resistor divider (R14, R15):
    R14=30.1kOhm, R15=10.0kOhm (both 0.1% 0603). Sets hold-up trigger
    at 4.81V (calc: Vthr=1.2V, rat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
2026-04-04 fix: resolve MD013 line-length violations across all markdown files
    - Add tables:false and code_blocks:false to MD013 config (ASCII art + BOM tables exempt)
    - Wrap all prose lines exceeding 200 characters at natural word boundaries
    - Affects: README.md, Design_Log.md, Boards_Overview.md, Power_Module/Design_Spec.md,
    User_Manual.md, GUI_App/Design_Spec.md, Certification_Evidence.md
2026-04-04 fix: redraw Power Flow diagram as clean vertical top-down layout
    Replace ambiguous horizontal ASCII flow (misaligned eFuse junction) with a
    clear top-down power tree: inputs -> OR-ing -> TCO -> eFuse -> Dual Buck ->
    5V_MAIN -> distribution. All component designators and values verified
    against BOM.
2026-04-04 fix: resolve MD012 multiple-blank-lines violations across all markdown files
    Collapse all runs of 2+ consecutive blank lines to a single blank line.
    Likely introduced by MD032/MD058 blank-line insertion passes.
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2026-04-04 feat: specify keyboard switches (DPDT 6-pin, gadgetkingdom eBay)
    SW1-64: DPDT 2-pole 6-pin momentary push buttons (already purchased).
    Pole 1 (COM1+NO1) used for key-press sensing to CPLD inputs;
    Pole 2 reserved for lamp co-location / redundancy in future.
    Connected via 6.35mm spade-terminal harness same as plugboard jacks.
    New blade terminal rows BT129-256 (128 total, Keystone 1285):
    - Row 3 BT129-192: KEY_COM lines
    - Row 4 BT193-256: KEY_NO lines (active-low CPLD inputs)
    Total PCB blade terminals on Encoder board: 256 (4 rows of 64).
    Updated:
    - Encoder/Design_Spec.md: SW1-64 BOM row, BT129-256, keyboard
    switch wiring detail in section 3 Interconnects
    - Boards_Overview.md: replace stal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
2026-04-04 fix: clarify keyboard switch wiring - one pole electrical, one pole mechanical anchor
    Pole 1 (COM1+NO1): key-press signal to CPLD only.
    Pole 2 pins: soldered to PCB for physical key anchoring only,
    no electrical connection - not reserved for lamp/redundancy.
    NC1 not connected.
    Keys connect solely to keyboard Encoder board;
    no direct switch connection to Lightboard.
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2026-04-04 fix(connectors): Power Module and Stator J1 -> ERM8 male; Controller J1+J2 -> ERF8 female (CRIT-01)
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2026-04-04 fix(efuse): correct UVLO R1 from 732kOhm to 232kOhm for 11V threshold (CRIT-03)
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2026-04-04 fix(power-module): apply MOD-01 through MOD-16 from deep-dive review
    MOD-01: Consolidated BOM U10 package -> WQFN-20 (TPS23730RMTR)
    MOD-02: Consolidated BOM U9 package -> QFN-16
    MOD-03: Design_Spec D2 package -> SOT-553
    MOD-04: Board_Layout supercap -> C_SC1-4, 2x2, 11F/5.4V 2S2P
    MOD-05: Board_Layout JST-PH -> J3 Molex 43650-0519
    MOD-06: Clarify L1/L2 post-OR-ing placement note
    MOD-07: Add Bob Smith R18-R21 + C25 to BOM
    MOD-08: Fix R3 annotation (GND) -> (OVLO) in trace diagram
    MOD-09: Consolidated BOM U1 -> TPS259803ONRGER
    MOD-10: Harmonize U7 -> TPS7A8333PRMWR
    MOD-11: Harmonize U5 primary -> STUSB4500LQTR
    MOD-12: Flag JLCPCB search needed for 22uF 1210 caps
    MOD-13: Fix R7/R8 tolerance 0.1%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
2026-04-04 fix(bom): replace unavailable 22µF 50V 1210 with Samsung CL32B226KAJNNNE 25V
    GRM32ER71H226KE15L (22µF 50V X7R 1210) is not available from any
    distributor. Max actual bus voltage is ~16.4V (4S LiPo per DEC-005),
    so 25V gives 1.5x derating - adequate for prototype stage.
    Replacement: Samsung CL32B226KAJNNNE (22µF 25V X7R 1210)
    Mouser: 187-CL32B226KAJNNNE
    DigiKey: 1276-1935-1-ND
    JLCPCB: C21397 (user-found, verify specs before ordering)
    Affects C1, C4, C7, C8, C9, C10, C11, C12, C14 (9 positions).
    Updated BOM note with DC bias derating warning (~50-65% at 16V).
    Also fixed:
    - MIN-02: C2/C5/C23 Mouser PN KA2L -> KA12L (missing digit)
    - MIN-03: Board_Layout Power Flow OVP -> OVLO (wrong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
2026-04-04 Remove incorrect USB 3.0 and HDMI SI specs from Power Module
    USB-C on Power Module is power-delivery only (PD via TPS25751DREFR).
    No USB data lines or HDMI are routed on this board. Added clarifying
    note to prevent future confusion.
2026-04-04 Fix 3V3_SYSTEM->3V3_ENIG refs; add SW power docs and toggle switch spec
    - Replace stale 3V3_SYSTEM rail name with 3V3_ENIG across spec files
    (Controller, JTAG_Daughterboard, Stator, Boards_Overview)
    - Create design/Software/Linux_OS/Power_Management.md: Option C
    power management (LTC3350 I2C daemon + PWR_GD gpio-shutdown backstop)
    - Power_Module: SW1 (power toggle) and SW2 (hard reset) added to §1
    Safe-Start and BOM; toggle switch rated 10A/20V, series with VIN_BUS
    - Controller: R3 PWR_GD pull-up (10kΩ to 3V3_ENIG) added to BOM;
    GPIO reference corrected to 3V3_ENIG
2026-04-04 RGB switch LED circuit: SW1 EN-pin approach with CM5/hardware handoff
    - SW1 redesigned: EN-pin control (low-current) + Marquardt 1800 RGB
    rocker. No longer a high-current series switch in VIN_BUS path.
    - RGB LED circuit: MIC1555 -> Q_HW (BSS138) -> BAT54 diodes -> R+G
    (orange flash, pre-boot). CM5 GPIO 24 (SW_LED_CTRL) cuts hardware
    path; CM5 GPIOs 17/18/19 (SW_LED_R/G/B) drive switch LED directly.
    - Colour scheme: orange flash=booting, green=USB-C, blue=PoE,
    solid orange=battery, red=fault/shutdown.
    - Controller GPIO table: GPIO 17/18/19 renamed to SW_LED_R/G/B;
    GPIO 24 (SW_LED_CTRL) added.
    - BtB Link-Alpha: pins 31/32/33 -> SW_LED_R/G/B (was STATUS_AMBER/
    GREEN/RED with stale G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
2026-04-04 Review fixes: GPIO matrix, BtB pins 29/30/38/48, Stator J5->16-pin, ETH_LED direction
    - Controller GPIO matrix: fix 22->USB_FAULT (local), 23->BATT_PRES_N (BtB 45);
    add GPIO 25=SYS_FAULT (BtB pin 29). Update L4 plane name 5V_SYSTEM->5V_MAIN.
    - BtB Link-Alpha: pins 29=SYS_FAULT, 30=POE_STAT, 38=USB_STAT (freed from
    redundant GND isolation moat/shield); pin 48=GND (zone separator).
    - Pin 25/26 direction corrected: CTRL->PM (CM5 GbE PHY drives RJ45 LEDs on PM).
    - PM Board_Layout: add pins 29/30/38/46/47/48 to Trace Connections table;
    fix pin 34 formatting; add SYS_FAULT/POE_STAT/USB_STAT to Handshake diagram.
    - JTAG Daughterboard: fix crystal frequency 12MHz->24MHz in section 1.
    - Stator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
2026-04-04 Lint: fix MD001/MD004/MD013/MD032 warnings introduced by review fix agents
    - Stator/Design_Spec.md: wrap 444-char GND bond line (MD013)
    - Stator/Board_Layout.md: J5 heading ### -> ## to fix H1->H3 skip (MD001)
    - Reflector/Design_Spec.md: dashes -> asterisks in J1 sub-list (MD004);
    add blank line before bullet list after blockquote (MD032);
    wrap 311-char GND bond line (MD013)
    - Controller/Board_Layout.md: wrap 272-char RGB note blockquote (MD013)
    - JTAG_Daughterboard/Design_Spec.md: wrap 290-char GND bond line (MD013)
2026-04-04 docs(electronics): clean up overview docs formatting and structure
    - Boards_Overview.md: remove emoji from headings; add header block;
    fix section numbering; convert dash lists to asterisks
    - Electrical_Design.md: fix section gap (s8 -> s2); add header block;
    add cross-ref note
    - Consolidated_BOM.md: add header block; fix orphaned content;
    add overview section; line length and list style fixes
2026-04-04 docs(boards): professional restructure of six board Design_Specs
    Apply consistent professional structure across Stator, Reflector,
    JTAG Daughterboard, Encoder, Rotor, and Extension Design_Specs:
    - Add standard header block (Status/Version/Rev/Date) to each file
    - Fix heading hierarchy (no H1->H3 jumps, no duplicate H2 numbers)
    - Convert all list '-' bullets to '*' asterisks (MD004)
    - Ensure all lines within 200-char markdownlint limit (MD013)
    - Fix blank lines around blockquotes/lists (MD032)
    - Integrate GND bond and other recently added sections naturally
    - Add Design_Log.md cross-ref note to each file
    - No content removed from any file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
2026-04-04 ci(wiki): fix cross-reference link resolution in wiki-sync workflow
    Replace broken single-pass regex with path-aware resolver:
    - Build repo-path -> wiki-name map by walking design/ directory,
    mirroring the bash flatten rules (strip 'design/', / -> -, _ -> -)
    - Resolve each [text](href) link against the source file's original
    directory using os.path.normpath, handling any depth of ../
    - Separate fragment anchors (#section) before resolution so links
    like [text](file.md#heading) are converted correctly
    - Special-case Home.md (README.md) and _Sidebar.md mappings
    - Leave external URLs, bare anchors, and unresolvable links unchanged
    (silent no-op rather than corrupting the link)
    - Switch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
2026-04-04 docs(pm): restructure Design_Spec with corrected sections and BOM refs
    - Fix DEC-001 regression: replace old 3V3_SYSTEM note with correct
    DEC-001 reference (3V3_SYSTEM retired, 3V3_ENIG is unified rail)
    - Add supercap block layout detail (pitch, rib clearway, shadow zone)
    to PCB Architecture section
    - Replace misplaced Thermal Budget subsection with new Signal
    Integrity & Safety subsection (ESD D1-D5 details, grounding,
    single-point GND bond, galvanic isolation)
    - Remove orphaned duplicate sections (Power Architecture, Mechanical
    Spacing, Routing Constraints) that duplicated PCB Architecture
    - Move Thermal Budget to top-level section after Power Sequencing
    - Rename Power Sequencing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
2026-04-04 design: reduce LINK-BETA to 40-pin (ERF8-020 / ERM8-020)
    DEC-015: LINK-BETA connector reduced from 80-pin to 40-pin.
    Logic boards (Stator, Encoder, Reflector, Extension) are 3V3-only;
    no 5V_MAIN needed. Exact 40-pin signal allocation:
    Pins 1-9: JTAG chain + Reset (GND-shielded, 5 internal GND pins)
    Pins 10-11: 2-pin GND isolation moat
    Pins 12-17: ENC_IN[0:5] (CTRL->Stator)
    Pin 18: GND (IN/OUT inter-group shield)
    Pins 19-24: ENC_OUT[0:5] (Stator->CTRL)
    Pin 25: GND (OUT/TDO shield)
    Pin 26: TDO_RETURN (short-path bypass of rotor stack)
    Pin 27: GND (TDO shield)
    Pins 28-35: 3V3_ENIG x8 (4.0A capacity, adequate for 30-rotor)
    Pins 36-40: GND power return x5
    Poka-yoke: 80-pin LIN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
2026-04-04 docs(pm): wrap long blockquote lines to fix MD013 lint warnings
    Lines 415 and 425 (Q1-Q3 and C15-C25 BOM notes) exceeded 200 chars.
    Wrapped at natural sentence boundaries; no content changed.
2026-04-04 fix(controller): replace stale FTSH connector references with ERF8-020
    Three locations updated:
    - §2.2 High-Speed Interconnect: replaced FTSH-RA / THR clips / wrong
    pin groups (5A Rotor Rail) with ERF8-020 specs and correct 40-pin
    summary (JTAG block, ENC_IN/OUT, 3V3_ENIG power, GND returns)
    - §2.3 Physical Placement: '80-pin Samtec' -> '40-pin Samtec ERF8-020
    (LINK-BETA)' for Stator Link
    - §7 Connectivity: renamed section 'Mating Header (Samtec FTSH)' and
    replaced FTSH-120-01-L-DH part number with correct ERF8-020 specs
    (part number, pitch, stack height, mating part, assembly notes)
2026-04-04 design: assign GPIO 26 = SYS_RESET_N and propagate across stack
    - Controller Design_Spec: add GPIO 26 = SYS_RESET_N (Output, active-low)
    to GPIO mapping table; broadcast to all CPLDs via LINK-BETA pin 8,
    Extension Ports, and Encoder Ports
    - Controller/Stator Board_Layout: rename RST -> SYS_RESET_N on LINK-BETA
    pin 8 with updated description
    - Stator Board_Layout: rename J2-J4 'Satellite Links' -> 'Extension Ports';
    replace old stale 40-pin description with pending-spec note documenting
    the 3-connector rotor interface (ENC-IN / ENC-OUT / PWR+JTAG) and
    positional identity requirement across Stator / Extension / Reflector;
    update J5 Extension Port pin 2 GND -> SYS_RESET_N; update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
2026-04-30 Electronics deep-review Pass 1: 42 findings resolved
    - Power Module: SMBJ18A-Q TVS diode added (D4), ESD/thermal sections added
    - Controller: C26/C27 100nF per-IC bypass caps added to Design_Spec and Board_Layout
    - JTAG Daughterboard: Y1 crystal replaced with CTS 435F12012IET (verified 12MHz); bypass caps C1/C2 corrected to 15pF; new datasheets added
    - Stator: TVS arrays U9-U16 added to Board_Layout; ESD/thermal sections added; I2C pull-up resistors R3/R4 placed
    - Extension/Reflector: ESD and thermal sections added to both boards
    - Settings Board: ESD section added; connector signal names corrected
    - Rotor: ESD arrays U5-U12 added to Board_Layout
    - Actuation Module: R6 removed (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
    [EnigmaNG-PowerModule.kicad_pcb]
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
